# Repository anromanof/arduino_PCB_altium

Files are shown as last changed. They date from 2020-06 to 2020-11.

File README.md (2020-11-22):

# arduino_PCB_altium

Here are the resulting 3D model pictures for quick view. STEP files and 3D pdf's can be found in the corresponding project folder.

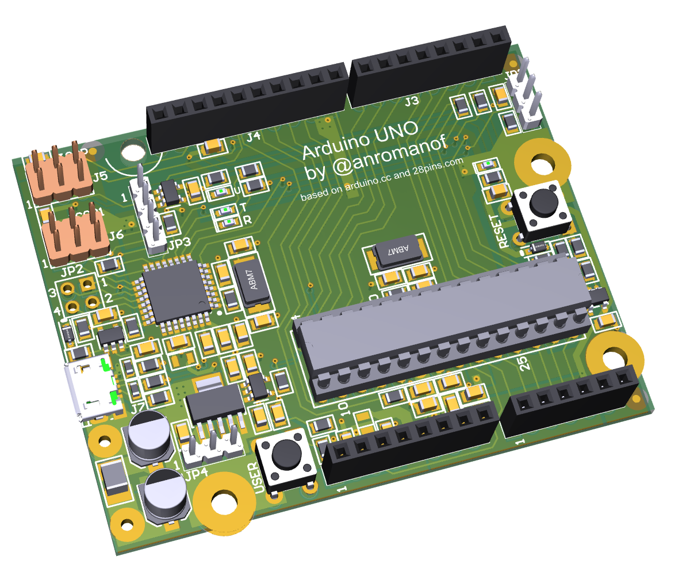
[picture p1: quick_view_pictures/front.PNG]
front


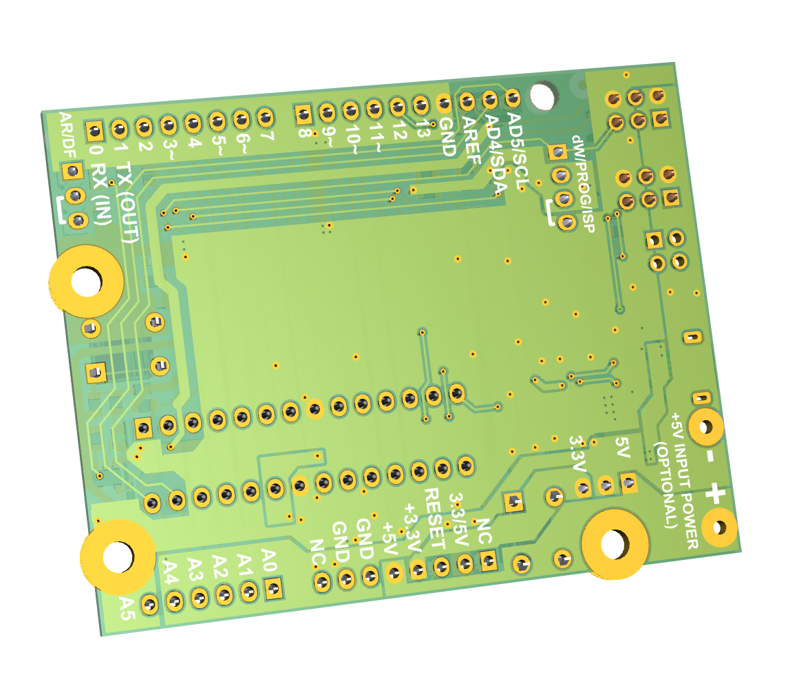
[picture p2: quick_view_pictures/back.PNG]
back


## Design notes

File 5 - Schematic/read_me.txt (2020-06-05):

Update Schematic Cover Page to RELEASED DD-MMM-YYYY
Here is the PDF version of schematic(one for each BOM variant if possible).

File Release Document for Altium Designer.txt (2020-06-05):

Follow this procedure before releasing files. Confirm every action with your initials and date.
IF ANY CHANGES NEEDS TO BE DONE, START THE PROCEDURE FROM BEGINNING!

The procedure needs to be executed in order as defined here. Start from number 1
--------------------------------------------------------------------------------

1) Right Click on the project -> Compile PCB project
I confirm, the project compiles with no errors: 
NR [4-June-2020]

2) Run Design -> Update PCB Document
I confirm, there are no differences between Schematic and PCB: 
NR [4-June-2020]

3) Impedance
I confirm, I have updated and check track width/gap to match required impedance (e.g 55 OHMs): 
NR [4-June-2020]

4) Run Tools -> Polygon Pours -> Rebuild All
I confirm, all polygons have been repoured: 
NR [4-June-2020]

5) Run Tools -> Design Rule Check -> Run Design Rule Check
I confirm, I have checked Design Rule Output File:
NR [4-June-2020]

6) Gerber check
I confirm, I have copied and visually checked gerber files placed in \PCB Manufacturing\Gerber Output\
NR [4-June-2020]

7) Other files
I confirm, I have copied and checked files placed in subdirectories:
NR [4-June-2020]

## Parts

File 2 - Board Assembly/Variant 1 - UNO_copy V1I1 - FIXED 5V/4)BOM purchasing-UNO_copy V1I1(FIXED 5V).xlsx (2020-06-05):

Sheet: Part List Report
 | Component list |  |  | Bill of Materials for Variant [FIXED 5V] of Project [UNO_copy V1I1.PrjPcb] (PCB Document : UNO_copy V1I1_PCB.PcbDoc)
 | Source Data From: | UNO_copy V1I1.PrjPcb |  |  | Contact: |  |  |  | Template created by:
 | Project: | UNO_copy V1I1.PrjPcb
 | Variant: | FIXED 5V |  |  |  |  |  |  | FEDEVEL
 | Report Date: | 6/4/2020 | 10:48 PM |  |  |  |  |  | http://www.fedevel.com
 | Print Date: | 2020-06-04 | 22:48:25
# | Category | Manufacturer 1 | Manufacturer Part Number 1 | Case/Package | Description | Quantity | Supplier 1 | Supplier Part Number 1 | Supplier Order Qty 1 | Supplier Stock 1 | Supplier Unit Price 1 | Supplier Subtotal 1 | Supplier Currency 1
1 | Voltage Regulators - Linear | Texas Instruments | TL1963A-33DCQR | SOT-223 | IC REG LINEAR 3.3V 1.5A SOT223-6 | 1 | Digi-Key | 296-24534-1-ND | 10 | 3415 | 2.51 | 25.13 | USD
2 | Varistors | Bourns | CG0603MLC-05E | 0603 | VARISTOR 0603 | 2 | Digi-Key | CG0603MLC-05ECT-ND | 20 | 11272 | 0.36 | 7.18 | USD
3 | USB Connectors | AMPHENOL ICC (FCI) | 10118193-0001LF |  | CONN USB MICRO B RECPT SMT R/A | 1 | Digi-Key | 609-4616-1-ND | 10 | 147829 | 0.41 | 4.05 | USD
4 | Schottky Diodes | ON Semiconductor / Fairchild | BAT54HT1G |  | Small Signal Schottky Diode, Single, 30 V, 200 mA, 800 mV, 600 mA, 150 C ;RoHS Compliant: Yes | 2 | Digi-Key | BAT54HT1GOSCT-ND | 20 | 328630 | 0.18 | 3.62 | USD
5 | Pushbutton Switches | ALCOSWITCH - TE CONNECTIVITY | 1825910-6 |  | SWITCH TACTILE SPST-NO 0.05A 24V | 2 | Digi-Key | 450-1650-ND | 20 | 25452 | 0.10 | 2.02 | USD
6 | Microcontrollers | Microchip | ATMEGA328P-PU | PDIP | ATMEGA328P-PU; 8 bit Microcontroller AVR 20MHz 1; 32kb Flash; 2kb RAM; I2C SPI 2 | 1 | Digi-Key | ATMEGA328P-PU-ND | 10 | 6233 | 2.08 | 20.80 | USD
7 | Microcontrollers | Microchip | ATMEGA16U2-AU | A | MICROCHIP - ATMEGA16U2-AU - MCU, 8BIT, MEGAAVR, 16MHZ, TQFP-32 | 1 | Digi-Key | ATMEGA16U2-AU-ND | 10 | 3462 | 2.45 | 24.50 | USD
8 | Logic Gates | Texas Instruments | SN74AHC1G09DBVR | SOT-23 | TEXAS INSTRUMENTS - SN74AHC1G09DBVR - AND Gate, 74AHC1G09, 2 Input, 2 V to 5.5 V, SOT-23-5 | 4 | Digi-Key | 296-29202-1-ND | 40 | 27709 | 0.21 | 8.40 | USD
9 | Headers and Wire Housings | Harwin | M20-7820842 | SIL | 2.54mm (0.1") Pitch SIL Vertical PC Tail Socket Assembly, selective gold + tin, 8 contacts | 2 | Digi-Key | 952-1823-ND | 20 | 0 | 0.97 | 19.44 | USD
10 | Headers and Wire Housings | Harwin | M20-7820646 | SIL | 06-WAY SIL VERT SOCKET L/FREE | 1 | Digi-Key | 952-1809-ND | 10 | 1249 | 0.84 | 8.42 | USD
11 | Headers and Wire Housings | Amphenol ICC | 67997-106HLF |  | CONN HEADER 6POS .100 STR 30AU | 2 | Digi-Key | 609-3393-ND | 20 | 1665 | 1.61 | 32.28 | USD
12 | Headers and Wire Housings | Amphenol FCI | 68001-204HLF |  | CONN HEADER VERT 4POS 2.54MM | 1 | Digi-Key | 609-3402-ND | 10 | 3614 | 0.36 | 3.57 | USD
13 | Headers and Wire Housings | Amphenol ICC | 68000-103HLF |  | Conn Unshrouded Header HDR 3 POS 2.54mm Solder ST Thru-Hole Bulk | 1 | Digi-Key | 609-3461-ND | 10 | 15419 | 0.28 | 2.79 | USD
14 | Headers and Wire Housings | Harwin | M20-7821046 | SIL | HARWIN - M20-7821046 - Board-To-Board Connector, M20 Series, Through Hole, Receptacle, 10, 2.54 mm, Tin Plated Contacts | 1 | Digi-Key | 952-1847-ND | 10 | 431 | 1.12 | 11.22 | USD
15 | Fixed Inductors | KEMET | L1210R2R2MDWIT | 1210 | FIXED IND 2.2UH 2A 80 MOHM SMD | 1 | Digi-Key | 399-9598-1-ND | 10 | 660 | 0.48 | 4.79 | USD
16 | Ferrite Beads and Chips | TDK | MPZ2012S601AT000 | 0805 | FERRITE BEAD 600 OHM 0805 1LN | 3 | Digi-Key | 445-2206-1-ND | 30 | 224816 | 0.07 | 2.11 | USD
17 | Diodes | Osram Opto | LGL29K-G2J1-24-Z | 0603 | LED Uni-Color Green 572nm 2-Pin Chip 0603(1608Metric) T/R | 1 | Digi-Key | 475-2709-1-ND | 10 | 120445 | 0.30 | 3.04 | USD
18 | Diodes | Osram Opto | LOL29K-H2K1-24-Z | 0603 | OSRAM - LO L29K-H2K1-24-Z - SMARTLED 0603 ORANGE | 3 | Digi-Key | 475-2740-2-ND |  | 10000 |  |  | USD
19 | Crystals | Abracon | ABM7-16.000MHZ-D2Y-T | CSMD | CRYSTAL 16.0000MHZ 18PF SMD | 2 | Digi-Key | 535-9840-1-ND | 20 | 65890 | 0.89 | 17.72 | USD
20 | Connectors | 3M | 7010501790 |  | CONN IC DIP SOCKET 28POS TIN | 1 | Digi-Key | 3M5480-ND | 10 | 4763 | 0.69 | 6.93 | USD
21 | Connectors | Sullins | QPC02SXGN-RC | 100 | CONN JUMPER SHORTING .100" GOLD | 2 | Digi-Key | S9337-ND | 20 | 389812 | 0.06 | 1.18 | USD
22 | Chip SMD Resistors | Yageo | RC0805FR-071ML | 0805 | RES SMD 1M OHM 1% 1/8W 0805 | 2 | Digi-Key | 311-1.00MCRCT-ND | 20 | 3478595 | 0.04 | 0.80 | USD
23 | Chip SMD Resistors | Yageo | RC0805FR-0710KL | 0805 | RES SMD 10K OHM 1% 1/8W 0805 | 6 | Digi-Key | 311-10.0KCRDKR-ND | 60 | 22153735 | 0.04 | 2.40 | USD
24 | Chip SMD Resistors | Yageo | RC0805FR-0722RL | 0805 | RES SMD 22 OHM 1% 1/8W 0805 | 7 | Digi-Key | 311-22.0CRCT-ND | 70 | 528696 | 0.04 | 2.80 | USD
25 | Chip SMD Resistors | Yageo | RC0805FR-07560RL | 0805 | Res Thick Film 0805 560 Ohm 1% 0.125W(1/8W) ±100ppm/C Pad SMD T/R | 5 | Digi-Key | 311-560CRCT-ND | 50 | 203177 | 0.04 | 2.00 | USD
26 | Chip SMD Resistors | Yageo Phycomp | RC0805FR-071KL | 0805 | RESISTOR, 0805 1K 1%, FULL REEL; Product Range:YAGEO - RC Series; Resistance:1kohm; Power Rating:125mW; Resistance Tolerance:± 1%; Resistor Case Style:0805 [2012 Metric]; Resistor Element Material:Thick Film; Temperature Coefficient:± 250ppm/°C; Voltage Rating:150V; Packaging:Tape & Reel; MSL:-; SVHC:No SVHC (16-Dec-2013); External Depth:0.55mm; External Length / Height:2mm; External Width:1.25mm; No. of Pins:2; Operating Temperature Max:155°C; Operating Temperature Min:-55°C; Operating Temperature Range:-55°C to +155°C; Reel Quantity:5000; Resistor Mounting:SMD; Series:RC12H; Temperature Coef | 3 | Digi-Key | 311-1.00KCRTR-ND |  | 19687706 |  |  | USD
27 | Chip SMD Resistors | Yageo | RC0805JR-070RL | 0805 | Surface Mount Thick Film Resistor, RC Series, 125 mW, - 5%, 150 V, 0805 [2012 Metric] | 2 | Digi-Key | 311-0.0ARCT-ND | 20 | 7980293 | 0.04 | 0.70 | USD
28 | Chip SMD Resistors | Yageo | RC0805FR-07100KL | 0805 | YAGEO RC0805FR-07100KL RES, THICK FILM, 100K, 1%, 0.125W, 0805, REEL | 1 | Digi-Key | 311-100KCRCT-ND | 10 | 4686552 | 0.04 | 0.40 | USD
29 | Ceramic Capacitors | KEMET | C0805C180J5GACTU | 0805 | CAP CER 18PF 50V C0G/NP0 0805 | 4 | Digi-Key | 399-1112-1-ND | 40 | 169363 | 0.10 | 4.00 | USD
30 | Ceramic Capacitors | TDK | C2012X5R1C106K085AC | 0805 | TDK - C2012X5R1C106K085AC - SMD Multilayer Ceramic Capacitor, 10 µF, 16 V, 0805 [2012 Metric], ± 10%, X5R, C Series TDK | 7 | Digi-Key | 445-7644-1-ND | 70 | 1456223 | 0.17 | 12.25 | USD
31 | Ceramic Capacitors | TDK | C2012X5R1E105K125AA | 0805 | TDK - C2012X5R1E105K125AA - SMD Multilayer Ceramic Capacitor, 1 µF, 25 V, 0805 [2012 Metric], ± 10%, X5R, C Series | 1 | Digi-Key | 445-1419-1-ND | 10 | 29808 | 0.18 | 1.82 | USD
32 | Ceramic Capacitors | TDK | C2012X7R1H104K085AA | 0805 | TDK - C2012X7R1H104K085AA - SMD Multilayer Ceramic Capacitor, 0.1 µF, 50 V, 0805 [2012 Metric], ± 10%, X7R, C Series | 19 | Digi-Key | 445-7534-1-ND | 190 | 241464 | 0.06 | 10.66 | USD
33 | Aluminum Electrolytic Capacitors | Panasonic | EEE-1AA101WR | Radial | Cap Aluminum 100uF 10V 20% (5 X 5.4mm) SMD 50mA 1000 hr 85°C T/R | 2 | Digi-Key | PCE3867CT-ND | 20 | 60146 | 0.22 | 4.42 | USD
 |  |  |  |  |  | 94 |  |  | 880 |  |  | 251.44
Approved |  |  |  | Notes
 |  |  |  |  |  | 10 | pcs: | Total |  | 251.44 |  | USD
 |  |  |  |  |  |  |  | Price for 1pcs |  | 25.14 |  | USD

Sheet: Project Information
Project Full Path | C:\Users\Public\Documents\Altium\Projects\UNO_COPY\UNO_copy V1I1.PrjPcb
Project Filename | UNO_copy V1I1.PrjPcb
Variant Name | FIXED 5V
Data-Source Filename | UNO_copy V1I1.PrjPcb
Data-Source Full Path | C:\Users\Public\Documents\Altium\Projects\UNO_COPY\UNO_copy V1I1.PrjPcb
Title | Bill of Materials for Variant [FIXED 5V] of Project [UNO_copy V1I1.PrjPcb] (PCB Document : UNO_copy V1I1_PCB.PcbDoc)
Total Quantity | 94
Report Time | 10:48 PM
Report Date | 6/4/2020
Report Date & Tine | 6/4/2020 10:48 PM
Output Name | Bill of Materials
Output Type | BOM_PartType
Output Generator Name | BOM
Output Generator Description | Bill of Materials

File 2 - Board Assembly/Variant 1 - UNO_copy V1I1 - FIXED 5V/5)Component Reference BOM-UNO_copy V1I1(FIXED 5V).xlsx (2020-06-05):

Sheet: Part List Report
 | Component reference list |  |  | Uno Copy
 |  | Source Data From: | UNO_copy V1I1.PrjPcb |  | Contact: |  | Template created by:
 |  | Project: | UNO_copy V1I1.PrjPcb
 |  | Variant: | FIXED 5V |  |  |  | FEDEVEL
 | Report Date: | 6/4/2020 | 10:53 PM |  |  |  | http://www.fedevel.com
 | Print Date: | 2020-06-04 | 22:53:33
# | Designator | Comment | Description | Manufacturer 1 | Manufacturer Part Number 1 | Case/Package | Supplier 1 | Supplier Part Number 1
1 | C1 | 100uF / 10V | Cap Aluminum 100uF 10V 20% (5 X 5.4mm) SMD 50mA 1000 hr 85°C T/R | Panasonic | EEE-1AA101WR | Radial | Digi-Key | PCE3867CT-ND
2 | C2 | 100uF / 10V | Cap Aluminum 100uF 10V 20% (5 X 5.4mm) SMD 50mA 1000 hr 85°C T/R | Panasonic | EEE-1AA101WR | Radial | Digi-Key | PCE3867CT-ND
3 | C3 | 10uF / 16V | TDK - C2012X5R1C106K085AC - SMD Multilayer Ceramic Capacitor, 10 µF, 16 V, 0805 [2012 Metric], ± 10%, X5R, C Series TDK | TDK | C2012X5R1C106K085AC | 0805 | Digi-Key | 445-7644-1-ND
4 | C4 | 100nF | TDK - C2012X7R1H104K085AA - SMD Multilayer Ceramic Capacitor, 0.1 µF, 50 V, 0805 [2012 Metric], ± 10%, X7R, C Series | TDK | C2012X7R1H104K085AA | 0805 | Digi-Key | 445-7534-1-ND
5 | C5 | 100nF | TDK - C2012X7R1H104K085AA - SMD Multilayer Ceramic Capacitor, 0.1 µF, 50 V, 0805 [2012 Metric], ± 10%, X7R, C Series | TDK | C2012X7R1H104K085AA | 0805 | Digi-Key | 445-7534-1-ND
6 | C6 | 100nF | TDK - C2012X7R1H104K085AA - SMD Multilayer Ceramic Capacitor, 0.1 µF, 50 V, 0805 [2012 Metric], ± 10%, X7R, C Series | TDK | C2012X7R1H104K085AA | 0805 | Digi-Key | 445-7534-1-ND
7 | C7 | 1uF / 25V | TDK - C2012X5R1E105K125AA - SMD Multilayer Ceramic Capacitor, 1 µF, 25 V, 0805 [2012 Metric], ± 10%, X5R, C Series | TDK | C2012X5R1E105K125AA | 0805 | Digi-Key | 445-1419-1-ND
8 | C8 | 100nF | TDK - C2012X7R1H104K085AA - SMD Multilayer Ceramic Capacitor, 0.1 µF, 50 V, 0805 [2012 Metric], ± 10%, X7R, C Series | TDK | C2012X7R1H104K085AA | 0805 | Digi-Key | 445-7534-1-ND
9 | C9 | 18p | CAP CER 18PF 50V C0G/NP0 0805 | KEMET | C0805C180J5GACTU | 0805 | Digi-Key | 399-1112-1-ND
10 | C10 | 18p | CAP CER 18PF 50V C0G/NP0 0805 | KEMET | C0805C180J5GACTU | 0805 | Digi-Key | 399-1112-1-ND
11 | C11 | 100nF | TDK - C2012X7R1H104K085AA - SMD Multilayer Ceramic Capacitor, 0.1 µF, 50 V, 0805 [2012 Metric], ± 10%, X7R, C Series | TDK | C2012X7R1H104K085AA | 0805 | Digi-Key | 445-7534-1-ND
12 | C12 | 10uF / 16V | TDK - C2012X5R1C106K085AC - SMD Multilayer Ceramic Capacitor, 10 µF, 16 V, 0805 [2012 Metric], ± 10%, X5R, C Series TDK | TDK | C2012X5R1C106K085AC | 0805 | Digi-Key | 445-7644-1-ND
13 | C13 | 10uF / 16V | TDK - C2012X5R1C106K085AC - SMD Multilayer Ceramic Capacitor, 10 µF, 16 V, 0805 [2012 Metric], ± 10%, X5R, C Series TDK | TDK | C2012X5R1C106K085AC | 0805 | Digi-Key | 445-7644-1-ND
14 | C14 | 100nF | TDK - C2012X7R1H104K085AA - SMD Multilayer Ceramic Capacitor, 0.1 µF, 50 V, 0805 [2012 Metric], ± 10%, X7R, C Series | TDK | C2012X7R1H104K085AA | 0805 | Digi-Key | 445-7534-1-ND
15 | C15 | 100nF | TDK - C2012X7R1H104K085AA - SMD Multilayer Ceramic Capacitor, 0.1 µF, 50 V, 0805 [2012 Metric], ± 10%, X7R, C Series | TDK | C2012X7R1H104K085AA | 0805 | Digi-Key | 445-7534-1-ND
16 | C16 | 100nF | TDK - C2012X7R1H104K085AA - SMD Multilayer Ceramic Capacitor, 0.1 µF, 50 V, 0805 [2012 Metric], ± 10%, X7R, C Series | TDK | C2012X7R1H104K085AA | 0805 | Digi-Key | 445-7534-1-ND
17 | C17 | 100nF | TDK - C2012X7R1H104K085AA - SMD Multilayer Ceramic Capacitor, 0.1 µF, 50 V, 0805 [2012 Metric], ± 10%, X7R, C Series | TDK | C2012X7R1H104K085AA | 0805 | Digi-Key | 445-7534-1-ND
18 | C19 | 10uF / 16V | TDK - C2012X5R1C106K085AC - SMD Multilayer Ceramic Capacitor, 10 µF, 16 V, 0805 [2012 Metric], ± 10%, X5R, C Series TDK | TDK | C2012X5R1C106K085AC | 0805 | Digi-Key | 445-7644-1-ND
19 | C20 | 100nF | TDK - C2012X7R1H104K085AA - SMD Multilayer Ceramic Capacitor, 0.1 µF, 50 V, 0805 [2012 Metric], ± 10%, X7R, C Series | TDK | C2012X7R1H104K085AA | 0805 | Digi-Key | 445-7534-1-ND
20 | C21 | 10uF / 16V | TDK - C2012X5R1C106K085AC - SMD Multilayer Ceramic Capacitor, 10 µF, 16 V, 0805 [2012 Metric], ± 10%, X5R, C Series TDK | TDK | C2012X5R1C106K085AC | 0805 | Digi-Key | 445-7644-1-ND
21 | C22 | 10uF / 16V | TDK - C2012X5R1C106K085AC - SMD Multilayer Ceramic Capacitor, 10 µF, 16 V, 0805 [2012 Metric], ± 10%, X5R, C Series TDK | TDK | C2012X5R1C106K085AC | 0805 | Digi-Key | 445-7644-1-ND
22 | C23 | 100nF | TDK - C2012X7R1H104K085AA - SMD Multilayer Ceramic Capacitor, 0.1 µF, 50 V, 0805 [2012 Metric], ± 10%, X7R, C Series | TDK | C2012X7R1H104K085AA | 0805 | Digi-Key | 445-7534-1-ND
23 | C24 | 100nF | TDK - C2012X7R1H104K085AA - SMD Multilayer Ceramic Capacitor, 0.1 µF, 50 V, 0805 [2012 Metric], ± 10%, X7R, C Series | TDK | C2012X7R1H104K085AA | 0805 | Digi-Key | 445-7534-1-ND
24 | C25 | 18p | CAP CER 18PF 50V C0G/NP0 0805 | KEMET | C0805C180J5GACTU | 0805 | Digi-Key | 399-1112-1-ND
25 | C26 | 100nF | TDK - C2012X7R1H104K085AA - SMD Multilayer Ceramic Capacitor, 0.1 µF, 50 V, 0805 [2012 Metric], ± 10%, X7R, C Series | TDK | C2012X7R1H104K085AA | 0805 | Digi-Key | 445-7534-1-ND
26 | C27 | 18p | CAP CER 18PF 50V C0G/NP0 0805 | KEMET | C0805C180J5GACTU | 0805 | Digi-Key | 399-1112-1-ND
27 | C28 | 100nF | TDK - C2012X7R1H104K085AA - SMD Multilayer Ceramic Capacitor, 0.1 µF, 50 V, 0805 [2012 Metric], ± 10%, X7R, C Series | TDK | C2012X7R1H104K085AA | 0805 | Digi-Key | 445-7534-1-ND
28 | C29 | 100nF | TDK - C2012X7R1H104K085AA - SMD Multilayer Ceramic Capacitor, 0.1 µF, 50 V, 0805 [2012 Metric], ± 10%, X7R, C Series | TDK | C2012X7R1H104K085AA | 0805 | Digi-Key | 445-7534-1-ND
29 | C30 | 100nF | TDK - C2012X7R1H104K085AA - SMD Multilayer Ceramic Capacitor, 0.1 µF, 50 V, 0805 [2012 Metric], ± 10%, X7R, C Series | TDK | C2012X7R1H104K085AA | 0805 | Digi-Key | 445-7534-1-ND
30 | C31 | 100nF | TDK - C2012X7R1H104K085AA - SMD Multilayer Ceramic Capacitor, 0.1 µF, 50 V, 0805 [2012 Metric], ± 10%, X7R, C Series | TDK | C2012X7R1H104K085AA | 0805 | Digi-Key | 445-7534-1-ND
31 | C32 | 100nF | TDK - C2012X7R1H104K085AA - SMD Multilayer Ceramic Capacitor, 0.1 µF, 50 V, 0805 [2012 Metric], ± 10%, X7R, C Series | TDK | C2012X7R1H104K085AA | 0805 | Digi-Key | 445-7534-1-ND
32 | C33 | 100nF | TDK - C2012X7R1H104K085AA - SMD Multilayer Ceramic Capacitor, 0.1 µF, 50 V, 0805 [2012 Metric], ± 10%, X7R, C Series | TDK | C2012X7R1H104K085AA | 0805 | Digi-Key | 445-7534-1-ND
33 | C34 | 10uF / 16V | TDK - C2012X5R1C106K085AC - SMD Multilayer Ceramic Capacitor, 10 µF, 16 V, 0805 [2012 Metric], ± 10%, X5R, C Series TDK | TDK | C2012X5R1C106K085AC | 0805 | Digi-Key | 445-7644-1-ND
34 | D1 | Green | LED Uni-Color Green 572nm 2-Pin Chip 0603(1608Metric) T/R | Osram Opto | LGL29K-G2J1-24-Z | 0603 | Digi-Key | 475-2709-1-ND
35 | D2 | Orange | OSRAM - LO L29K-H2K1-24-Z - SMARTLED 0603 ORANGE | Osram Opto | LOL29K-H2K1-24-Z | 0603 | Digi-Key | 475-2740-2-ND
36 | D3 | Orange | OSRAM - LO L29K-H2K1-24-Z - SMARTLED 0603 ORANGE | Osram Opto | LOL29K-H2K1-24-Z | 0603 | Digi-Key | 475-2740-2-ND
37 | D4 | Orange | OSRAM - LO L29K-H2K1-24-Z - SMARTLED 0603 ORANGE | Osram Opto | LOL29K-H2K1-24-Z | 0603 | Digi-Key | 475-2740-2-ND
38 | D5 | BAT54HT1G | Small Signal Schottky Diode, Single, 30 V, 200 mA, 800 mV, 600 mA, 150 C ;RoHS Compliant: Yes | ON Semiconductor / Fairchild | BAT54HT1G |  | Digi-Key | BAT54HT1GOSCT-ND
39 | D6 | BAT54HT1G | Small Signal Schottky Diode, Single, 30 V, 200 mA, 800 mV, 600 mA, 150 C ;RoHS Compliant: Yes | ON Semiconductor / Fairchild | BAT54HT1G |  | Digi-Key | BAT54HT1GOSCT-ND
40 | FB1 | MPZ2012S601AT000 | FERRITE BEAD 600 OHM 0805 1LN | TDK | MPZ2012S601AT000 | 0805 | Digi-Key | 445-2206-1-ND
41 | FB2 | MPZ2012S601AT000 | FERRITE BEAD 600 OHM 0805 1LN | TDK | MPZ2012S601AT000 | 0805 | Digi-Key | 445-2206-1-ND
42 | FB3 | MPZ2012S601AT000 | FERRITE BEAD 600 OHM 0805 1LN | TDK | MPZ2012S601AT000 | 0805 | Digi-Key | 445-2206-1-ND
43 | J1 | HDR FMALE 1x8 2.54mm | 2.54mm (0.1") Pitch SIL Vertical PC Tail Socket Assembly, selective gold + tin, 8 contacts | Harwin | M20-7820842 | SIL | Digi-Key | 952-1823-ND
44 | J2 | HDR FMALE 1x6 2.54mm | 06-WAY SIL VERT SOCKET L/FREE | Harwin | M20-7820646 | SIL | Digi-Key | 952-1809-ND
45 | J3 | HDR FMALE 1x8 2.54mm | 2.54mm (0.1") Pitch SIL Vertical PC Tail Socket Assembly, selective gold + tin, 8 contacts | Harwin | M20-7820842 | SIL | Digi-Key | 952-1823-ND
46 | J4 | HDR FMALE 1x10 2.54mm | HARWIN - M20-7821046 - Board-To-Board Connector, M20 Series, Through Hole, Receptacle, 10, 2.54 mm, Tin Plated Contacts | Harwin | M20-7821046 | SIL | Digi-Key | 952-1847-ND
47 | J5 | HDR 2x3 | CONN HEADER 6POS .100 STR 30AU | Amphenol ICC | 67997-106HLF |  | Digi-Key | 609-3393-ND
48 | J6 | HDR 2x3 | CONN HEADER 6POS .100 STR 30AU | Amphenol ICC | 67997-106HLF |  | Digi-Key | 609-3393-ND
49 | J7 | 10118193-0001LF | CONN USB MICRO B RECPT SMT R/A | AMPHENOL ICC (FCI) | 10118193-0001LF |  | Digi-Key | 609-4616-1-ND
50 | JP1 | HDR 1x3 | Conn Unshrouded Header HDR 3 POS 2.54mm Solder ST Thru-Hole Bulk | Amphenol ICC | 68000-103HLF |  | Digi-Key | 609-3461-ND
51 | JP3 | HDR 1x4 | CONN HEADER VERT 4POS 2.54MM | Amphenol FCI | 68001-204HLF |  | Digi-Key | 609-3402-ND
52 | L1 | 2u2 / 2A | FIXED IND 2.2UH 2A 80 MOHM SMD | KEMET | L1210R2R2MDWIT | 1210 | Digi-Key | 399-9598-1-ND
53 | LINK1 | LINK | CONN JUMPER SHORTING .100" GOLD | Sullins | QPC02SXGN-RC | 100 | Digi-Key | S9337-ND
54 | LINK2 | LINK | CONN JUMPER SHORTING .100" GOLD | Sullins | QPC02SXGN-RC | 100 | Digi-Key | S9337-ND
55 | R1 | 100k | YAGEO RC0805FR-07100KL RES, THICK FILM, 100K, 1%, 0.125W, 0805, REEL | Yageo | RC0805FR-07100KL | 0805 | Digi-Key | 311-100KCRCT-ND
56 | R2 | 560R | Res Thick Film 0805 560 Ohm 1% 0.125W(1/8W) ±100ppm/C Pad SMD T/R | Yageo | RC0805FR-07560RL | 0805 | Digi-Key | 311-560CRCT-ND
57 | R3 | 560R | Res Thick Film 0805 560 Ohm 1% 0.125W(1/8W) ±100ppm/C Pad SMD T/R | Yageo | RC0805FR-07560RL | 0805 | Digi-Key | 311-560CRCT-ND
58 | R4 | 10k | RES SMD 10K OHM 1% 1/8W 0805 | Yageo | RC0805FR-0710KL | 0805 | Digi-Key | 311-10.0KCRDKR-ND
59 | R5 | 22R | RES SMD 22 OHM 1% 1/8W 0805 | Yageo | RC0805FR-0722RL | 0805 | Digi-Key | 311-22.0CRCT-ND
60 | R6 | 22R | RES SMD 22 OHM 1% 1/8W 0805 | Yageo | RC0805FR-0722RL | 0805 | Digi-Key | 311-22.0CRCT-ND
61 | R7 | 22R | RES SMD 22 OHM 1% 1/8W 0805 | Yageo | RC0805FR-0722RL | 0805 | Digi-Key | 311-22.0CRCT-ND
62 | R8 | 0R | Surface Mount Thick Film Resistor, RC Series, 125 mW, - 5%, 150 V, 0805 [2012 Metric] | Yageo | RC0805JR-070RL | 0805 | Digi-Key | 311-0.0ARCT-ND
63 | R9 | 1M | RES SMD 1M OHM 1% 1/8W 0805 | Yageo | RC0805FR-071ML | 0805 | Digi-Key | 311-1.00MCRCT-ND
64 | R10 | 1k | RESISTOR, 0805 1K 1%, FULL REEL; Product Range:YAGEO - RC Series; Resistance:1kohm; Power Rating:125mW; Resistance Tolerance:± 1%; Resistor Case Style:0805 [2012 Metric]; Resistor Element Material:Thick Film; Temperature Coefficient:± 250ppm/°C; Voltage Rating:150V; Packaging:Tape & Reel; MSL:-; SVHC:No SVHC (16-Dec-2013); External Depth:0.55mm; External Length / Height:2mm; External Width:1.25mm; No. of Pins:2; Operating Temperature Max:155°C; Operating Temperature Min:-55°C; Operating Temperature Range:-55°C to +155°C; Reel Quantity:5000; Resistor Mounting:SMD; Series:RC12H; Temperature Coef | Yageo Phycomp | RC0805FR-071KL | 0805 | Digi-Key | 311-1.00KCRTR-ND
65 | R11 | 1k | RESISTOR, 0805 1K 1%, FULL REEL; Product Range:YAGEO - RC Series; Resistance:1kohm; Power Rating:125mW; Resistance Tolerance:± 1%; Resistor Case Style:0805 [2012 Metric]; Resistor Element Material:Thick Film; Temperature Coefficient:± 250ppm/°C; Voltage Rating:150V; Packaging:Tape & Reel; MSL:-; SVHC:No SVHC (16-Dec-2013); External Depth:0.55mm; External Length / Height:2mm; External Width:1.25mm; No. of Pins:2; Operating Temperature Max:155°C; Operating Temperature Min:-55°C; Operating Temperature Range:-55°C to +155°C; Reel Quantity:5000; Resistor Mounting:SMD; Series:RC12H; Temperature Coef | Yageo Phycomp | RC0805FR-071KL | 0805 | Digi-Key | 311-1.00KCRTR-ND
66 | R12 | 1k | RESISTOR, 0805 1K 1%, FULL REEL; Product Range:YAGEO - RC Series; Resistance:1kohm; Power Rating:125mW; Resistance Tolerance:± 1%; Resistor Case Style:0805 [2012 Metric]; Resistor Element Material:Thick Film; Temperature Coefficient:± 250ppm/°C; Voltage Rating:150V; Packaging:Tape & Reel; MSL:-; SVHC:No SVHC (16-Dec-2013); External Depth:0.55mm; External Length / Height:2mm; External Width:1.25mm; No. of Pins:2; Operating Temperature Max:155°C; Operating Temperature Min:-55°C; Operating Temperature Range:-55°C to +155°C; Reel Quantity:5000; Resistor Mounting:SMD; Series:RC12H; Temperature Coef | Yageo Phycomp | RC0805FR-071KL | 0805 | Digi-Key | 311-1.00KCRTR-ND
67 | R13 | 22R | RES SMD 22 OHM 1% 1/8W 0805 | Yageo | RC0805FR-0722RL | 0805 | Digi-Key | 311-22.0CRCT-ND
68 | R14 | 10k | RES SMD 10K OHM 1% 1/8W 0805 | Yageo | RC0805FR-0710KL | 0805 | Digi-Key | 311-10.0KCRDKR-ND
69 | R15 | 560R | Res Thick Film 0805 560 Ohm 1% 0.125W(1/8W) ±100ppm/C Pad SMD T/R | Yageo | RC0805FR-07560RL | 0805 | Digi-Key | 311-560CRCT-ND
70 | R16 | 1M | RES SMD 1M OHM 1% 1/8W 0805 | Yageo | RC0805FR-071ML | 0805 | Digi-Key | 311-1.00MCRCT-ND
71 | R17 | 560R | Res Thick Film 0805 560 Ohm 1% 0.125W(1/8W) ±100ppm/C Pad SMD T/R | Yageo | RC0805FR-07560RL | 0805 | Digi-Key | 311-560CRCT-ND
72 | R18 | 10k | RES SMD 10K OHM 1% 1/8W 0805 | Yageo | RC0805FR-0710KL | 0805 | Digi-Key | 311-10.0KCRDKR-ND
73 | R19 | 10k | RES SMD 10K OHM 1% 1/8W 0805 | Yageo | RC0805FR-0710KL | 0805 | Digi-Key | 311-10.0KCRDKR-ND
74 | R20 | 10k | RES SMD 10K OHM 1% 1/8W 0805 | Yageo | RC0805FR-0710KL | 0805 | Digi-Key | 311-10.0KCRDKR-ND
75 | R21 | 10k | RES SMD 10K OHM 1% 1/8W 0805 | Yageo | RC0805FR-0710KL | 0805 | Digi-Key | 311-10.0KCRDKR-ND
76 | R22 | 560R | Res Thick Film 0805 560 Ohm 1% 0.125W(1/8W) ±100ppm/C Pad SMD T/R | Yageo | RC0805FR-07560RL | 0805 | Digi-Key | 311-560CRCT-ND
77 | R23 | 22R | RES SMD 22 OHM 1% 1/8W 0805 | Yageo | RC0805FR-0722RL | 0805 | Digi-Key | 311-22.0CRCT-ND
78 | R24 | 22R | RES SMD 22 OHM 1% 1/8W 0805 | Yageo | RC0805FR-0722RL | 0805 | Digi-Key | 311-22.0CRCT-ND
79 | R25 | 22R | RES SMD 22 OHM 1% 1/8W 0805 | Yageo | RC0805FR-0722RL | 0805 | Digi-Key | 311-22.0CRCT-ND
80 | R27 | 0R | Surface Mount Thick Film Resistor, RC Series, 125 mW, - 5%, 150 V, 0805 [2012 Metric] | Yageo | RC0805JR-070RL | 0805 | Digi-Key | 311-0.0ARCT-ND
81 | SCKT FOR U1 | 28-DIP Socket | CONN IC DIP SOCKET 28POS TIN | 3M | 7010501790 |  | Digi-Key | 3M5480-ND
82 | SW1 | 1825910-6 | SWITCH TACTILE SPST-NO 0.05A 24V | ALCOSWITCH - TE CONNECTIVITY | 1825910-6 |  | Digi-Key | 450-1650-ND
83 | SW2 | 1825910-6 | SWITCH TACTILE SPST-NO 0.05A 24V | ALCOSWITCH - TE CONNECTIVITY | 1825910-6 |  | Digi-Key | 450-1650-ND
84 | U1 | ATMEGA328P-PU | ATMEGA328P-PU; 8 bit Microcontroller AVR 20MHz 1; 32kb Flash; 2kb RAM; I2C SPI 2 | Microchip | ATMEGA328P-PU | PDIP | Digi-Key | ATMEGA328P-PU-ND
85 | U2 | ATMEGA16U2-AU | MICROCHIP - ATMEGA16U2-AU - MCU, 8BIT, MEGAAVR, 16MHZ, TQFP-32 | Microchip | ATMEGA16U2-AU | A | Digi-Key | ATMEGA16U2-AU-ND
86 | U3 | TL1963A-33DCQR | IC REG LINEAR 3.3V 1.5A SOT223-6 | Texas Instruments | TL1963A-33DCQR | SOT-223 | Digi-Key | 296-24534-1-ND
87 | U4 | SN74AHC1G09DBVR | TEXAS INSTRUMENTS - SN74AHC1G09DBVR - AND Gate, 74AHC1G09, 2 Input, 2 V to 5.5 V, SOT-23-5 | Texas Instruments | SN74AHC1G09DBVR | SOT-23 | Digi-Key | 296-29202-1-ND
88 | U5 | SN74AHC1G09DBVR | TEXAS INSTRUMENTS - SN74AHC1G09DBVR - AND Gate, 74AHC1G09, 2 Input, 2 V to 5.5 V, SOT-23-5 | Texas Instruments | SN74AHC1G09DBVR | SOT-23 | Digi-Key | 296-29202-1-ND
89 | U6 | SN74AHC1G09DBVR | TEXAS INSTRUMENTS - SN74AHC1G09DBVR - AND Gate, 74AHC1G09, 2 Input, 2 V to 5.5 V, SOT-23-5 | Texas Instruments | SN74AHC1G09DBVR | SOT-23 | Digi-Key | 296-29202-1-ND
90 | U7 | SN74AHC1G09DBVR | TEXAS INSTRUMENTS - SN74AHC1G09DBVR - AND Gate, 74AHC1G09, 2 Input, 2 V to 5.5 V, SOT-23-5 | Texas Instruments | SN74AHC1G09DBVR | SOT-23 | Digi-Key | 296-29202-1-ND
91 | Y1 | ABM7-16.000MHZ-D2Y-T | CRYSTAL 16.0000MHZ 18PF SMD | Abracon | ABM7-16.000MHZ-D2Y-T | CSMD | Digi-Key | 535-9840-1-ND
92 | Y2 | ABM7-16.000MHZ-D2Y-T | CRYSTAL 16.0000MHZ 18PF SMD | Abracon | ABM7-16.000MHZ-D2Y-T | CSMD | Digi-Key | 535-9840-1-ND
93 | Z1 | CG0603MLC-05E | VARISTOR 0603 | Bourns | CG0603MLC-05E | 0603 | Digi-Key | CG0603MLC-05ECT-ND
94 | Z2 | CG0603MLC-05E | VARISTOR 0603 | Bourns | CG0603MLC-05E | 0603 | Digi-Key | CG0603MLC-05ECT-ND
Approved |  |  |  | Notes

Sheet: Project Information
Project Full Path | C:\Users\Public\Documents\Altium\Projects\UNO_COPY\UNO_copy V1I1.PrjPcb
Project Filename | UNO_copy V1I1.PrjPcb
Variant Name | FIXED 5V
Data-Source Filename | UNO_copy V1I1.PrjPcb
Data-Source Full Path | C:\Users\Public\Documents\Altium\Projects\UNO_COPY\UNO_copy V1I1.PrjPcb
Title | UNO_copy V1I1.PrjPcb
Total Quantity | 94
Report Time | 10:53 PM
Report Date | 6/4/2020
Report Date & Tine | 6/4/2020 10:53 PM
Output Name | Component Reference BOM
Output Type | BOM_PartType
Output Generator Name | BOM
Output Generator Description | Bill of Materials

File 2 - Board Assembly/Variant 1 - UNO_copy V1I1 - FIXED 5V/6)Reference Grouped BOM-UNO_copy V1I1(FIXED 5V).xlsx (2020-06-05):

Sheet: Part List Report
 | Component reference list (grouped) |  |  |  | Uno Copy
 | Source Data From: |  | UNO_copy V1I1.PrjPcb |  |  | Contact: |  | Template created by:
 | Project: |  | UNO_copy V1I1.PrjPcb
 | Variant: |  | FIXED 5V |  |  |  |  | FEDEVEL
 | Report Date: |  | 6/4/2020 | 11:02 PM |  |  |  | http://www.fedevel.com
 | Print Date: |  | 2020-06-04 | 23:04:06
# | Designator | Quantity | Comment | Description | Manufacturer 1 | Manufacturer Part Number 1 | Case/Package | Supplier 1 | Supplier Part Number 1
1 | C1, C2 | 2 | 100uF / 10V | Cap Aluminum 100uF 10V 20% (5 X 5.4mm) SMD 50mA 1000 hr 85°C T/R | Panasonic | EEE-1AA101WR | Radial | Digi-Key | PCE3867CT-ND
2 | C3, C12, C13, C19, C21, C22, C34 | 7 | 10uF / 16V | TDK - C2012X5R1C106K085AC - SMD Multilayer Ceramic Capacitor, 10 µF, 16 V, 0805 [2012 Metric], ± 10%, X5R, C Series TDK | TDK | C2012X5R1C106K085AC | 0805 | Digi-Key | 445-7644-1-ND
3 | C4, C5, C6, C8, C11, C14, C15, C16, C17, C20, C23, C24, C26, C28, C29, C30, C31, C32, C33 | 19 | 100nF | TDK - C2012X7R1H104K085AA - SMD Multilayer Ceramic Capacitor, 0.1 µF, 50 V, 0805 [2012 Metric], ± 10%, X7R, C Series | TDK | C2012X7R1H104K085AA | 0805 | Digi-Key | 445-7534-1-ND
4 | C7 | 1 | 1uF / 25V | TDK - C2012X5R1E105K125AA - SMD Multilayer Ceramic Capacitor, 1 µF, 25 V, 0805 [2012 Metric], ± 10%, X5R, C Series | TDK | C2012X5R1E105K125AA | 0805 | Digi-Key | 445-1419-1-ND
5 | C9, C10, C25, C27 | 4 | 18p | CAP CER 18PF 50V C0G/NP0 0805 | KEMET | C0805C180J5GACTU | 0805 | Digi-Key | 399-1112-1-ND
6 | D1 | 1 | Green | LED Uni-Color Green 572nm 2-Pin Chip 0603(1608Metric) T/R | Osram Opto | LGL29K-G2J1-24-Z | 0603 | Digi-Key | 475-2709-1-ND
7 | D2, D3, D4 | 3 | Orange | OSRAM - LO L29K-H2K1-24-Z - SMARTLED 0603 ORANGE | Osram Opto | LOL29K-H2K1-24-Z | 0603 | Digi-Key | 475-2740-2-ND
8 | D5, D6 | 2 | BAT54HT1G | Small Signal Schottky Diode, Single, 30 V, 200 mA, 800 mV, 600 mA, 150 C ;RoHS Compliant: Yes | ON Semiconductor / Fairchild | BAT54HT1G |  | Digi-Key | BAT54HT1GOSCT-ND
9 | FB1, FB2, FB3 | 3 | MPZ2012S601AT000 | FERRITE BEAD 600 OHM 0805 1LN | TDK | MPZ2012S601AT000 | 0805 | Digi-Key | 445-2206-1-ND
10 | J1, J3 | 2 | HDR FMALE 1x8 2.54mm | 2.54mm (0.1") Pitch SIL Vertical PC Tail Socket Assembly, selective gold + tin, 8 contacts | Harwin | M20-7820842 | SIL | Digi-Key | 952-1823-ND
11 | J2 | 1 | HDR FMALE 1x6 2.54mm | 06-WAY SIL VERT SOCKET L/FREE | Harwin | M20-7820646 | SIL | Digi-Key | 952-1809-ND
12 | J4 | 1 | HDR FMALE 1x10 2.54mm | HARWIN - M20-7821046 - Board-To-Board Connector, M20 Series, Through Hole, Receptacle, 10, 2.54 mm, Tin Plated Contacts | Harwin | M20-7821046 | SIL | Digi-Key | 952-1847-ND
13 | J5, J6 | 2 | HDR 2x3 | CONN HEADER 6POS .100 STR 30AU | Amphenol ICC | 67997-106HLF |  | Digi-Key | 609-3393-ND
14 | J7 | 1 | 10118193-0001LF | CONN USB MICRO B RECPT SMT R/A | AMPHENOL ICC (FCI) | 10118193-0001LF |  | Digi-Key | 609-4616-1-ND
15 | JP1 | 1 | HDR 1x3 | Conn Unshrouded Header HDR 3 POS 2.54mm Solder ST Thru-Hole Bulk | Amphenol ICC | 68000-103HLF |  | Digi-Key | 609-3461-ND
16 | JP3 | 1 | HDR 1x4 | CONN HEADER VERT 4POS 2.54MM | Amphenol FCI | 68001-204HLF |  | Digi-Key | 609-3402-ND
17 | L1 | 1 | 2u2 / 2A | FIXED IND 2.2UH 2A 80 MOHM SMD | KEMET | L1210R2R2MDWIT | 1210 | Digi-Key | 399-9598-1-ND
18 | LINK1, LINK2 | 2 | LINK | CONN JUMPER SHORTING .100" GOLD | Sullins | QPC02SXGN-RC | 100 | Digi-Key | S9337-ND
19 | R1 | 1 | 100k | YAGEO RC0805FR-07100KL RES, THICK FILM, 100K, 1%, 0.125W, 0805, REEL | Yageo | RC0805FR-07100KL | 0805 | Digi-Key | 311-100KCRCT-ND
20 | R2, R3, R15, R17, R22 | 5 | 560R | Res Thick Film 0805 560 Ohm 1% 0.125W(1/8W) ±100ppm/C Pad SMD T/R | Yageo | RC0805FR-07560RL | 0805 | Digi-Key | 311-560CRCT-ND
21 | R4, R14, R18, R19, R20, R21 | 6 | 10k | RES SMD 10K OHM 1% 1/8W 0805 | Yageo | RC0805FR-0710KL | 0805 | Digi-Key | 311-10.0KCRDKR-ND
22 | R5, R6, R7, R13, R23, R24, R25 | 7 | 22R | RES SMD 22 OHM 1% 1/8W 0805 | Yageo | RC0805FR-0722RL | 0805 | Digi-Key | 311-22.0CRCT-ND
23 | R8, R27 | 2 | 0R | Surface Mount Thick Film Resistor, RC Series, 125 mW, - 5%, 150 V, 0805 [2012 Metric] | Yageo | RC0805JR-070RL | 0805 | Digi-Key | 311-0.0ARCT-ND
24 | R9, R16 | 2 | 1M | RES SMD 1M OHM 1% 1/8W 0805 | Yageo | RC0805FR-071ML | 0805 | Digi-Key | 311-1.00MCRCT-ND
25 | R10, R11, R12 | 3 | 1k | RESISTOR, 0805 1K 1%, FULL REEL; Product Range:YAGEO - RC Series; Resistance:1kohm; Power Rating:125mW; Resistance Tolerance:± 1%; Resistor Case Style:0805 [2012 Metric]; Resistor Element Material:Thick Film; Temperature Coefficient:± 250ppm/°C; Voltage Rating:150V; Packaging:Tape & Reel; MSL:-; SVHC:No SVHC (16-Dec-2013); External Depth:0.55mm; External Length / Height:2mm; External Width:1.25mm; No. of Pins:2; Operating Temperature Max:155°C; Operating Temperature Min:-55°C; Operating Temperature Range:-55°C to +155°C; Reel Quantity:5000; Resistor Mounting:SMD; Series:RC12H; Temperature Coef | Yageo Phycomp | RC0805FR-071KL | 0805 | Digi-Key | 311-1.00KCRTR-ND
26 | SCKT FOR U1 | 1 | 28-DIP Socket | CONN IC DIP SOCKET 28POS TIN | 3M | 7010501790 |  | Digi-Key | 3M5480-ND
27 | SW1, SW2 | 2 | 1825910-6 | SWITCH TACTILE SPST-NO 0.05A 24V | ALCOSWITCH - TE CONNECTIVITY | 1825910-6 |  | Digi-Key | 450-1650-ND
28 | U1 | 1 | ATMEGA328P-PU | ATMEGA328P-PU; 8 bit Microcontroller AVR 20MHz 1; 32kb Flash; 2kb RAM; I2C SPI 2 | Microchip | ATMEGA328P-PU | PDIP | Digi-Key | ATMEGA328P-PU-ND
29 | U2 | 1 | ATMEGA16U2-AU | MICROCHIP - ATMEGA16U2-AU - MCU, 8BIT, MEGAAVR, 16MHZ, TQFP-32 | Microchip | ATMEGA16U2-AU | A | Digi-Key | ATMEGA16U2-AU-ND
30 | U3 | 1 | TL1963A-33DCQR | IC REG LINEAR 3.3V 1.5A SOT223-6 | Texas Instruments | TL1963A-33DCQR | SOT-223 | Digi-Key | 296-24534-1-ND
31 | U4, U5, U6, U7 | 4 | SN74AHC1G09DBVR | TEXAS INSTRUMENTS - SN74AHC1G09DBVR - AND Gate, 74AHC1G09, 2 Input, 2 V to 5.5 V, SOT-23-5 | Texas Instruments | SN74AHC1G09DBVR | SOT-23 | Digi-Key | 296-29202-1-ND
32 | Y1, Y2 | 2 | ABM7-16.000MHZ-D2Y-T | CRYSTAL 16.0000MHZ 18PF SMD | Abracon | ABM7-16.000MHZ-D2Y-T | CSMD | Digi-Key | 535-9840-1-ND
33 | Z1, Z2 | 2 | CG0603MLC-05E | VARISTOR 0603 | Bourns | CG0603MLC-05E | 0603 | Digi-Key | CG0603MLC-05ECT-ND
Approved |  |  |  |  | Notes

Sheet: Project Information
Project Full Path | C:\Users\Public\Documents\Altium\Projects\UNO_COPY\UNO_copy V1I1.PrjPcb
Project Filename | UNO_copy V1I1.PrjPcb
Variant Name | FIXED 5V
Data-Source Filename | UNO_copy V1I1.PrjPcb
Data-Source Full Path | C:\Users\Public\Documents\Altium\Projects\UNO_COPY\UNO_copy V1I1.PrjPcb
Title | UNO_copy V1I1.PrjPcb
Total Quantity | 94
Report Time | 11:02 PM
Report Date | 6/4/2020
Report Date & Tine | 6/4/2020 11:02 PM
Output Name | Reference Grouped BOM
Output Type | BOM_PartType
Output Generator Name | BOM
Output Generator Description | Bill of Materials

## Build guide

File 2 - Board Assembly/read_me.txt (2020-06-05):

The following files are placed here:

- Mechanical Drawing (Board dimensions, holes position, ..)
- TOP and BOTTOM Assembly Drawing (Component position with Reference Designator)
- TOP and BOTTOM VIEW (shows board outline, assembly layer, TOP + BOTTOM layers)
- Bill of Materials (grouped by component type)
- Component reference BOM (each component on one line: Designator, Description, Manufacturer 1,
  Manufacturer, Part Number 1, Package / Case, Supplier 1, Supplier Part Number 1)
- Component reference BOM (as above) grouped by component type.
- Pick and Place
- TOP and BOTTOM Layer + TOP and BOTTOM Paste Gerber Files (for stencil - if panel is done in a PCB house, ask them later for the top/bottom layers and paste for the panel)
- PDF 3D Model

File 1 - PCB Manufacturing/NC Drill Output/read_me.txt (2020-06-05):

Here are the drill files and documents which explain it (e.g. for HDI PCB, pdf showing drills for each layer pair)

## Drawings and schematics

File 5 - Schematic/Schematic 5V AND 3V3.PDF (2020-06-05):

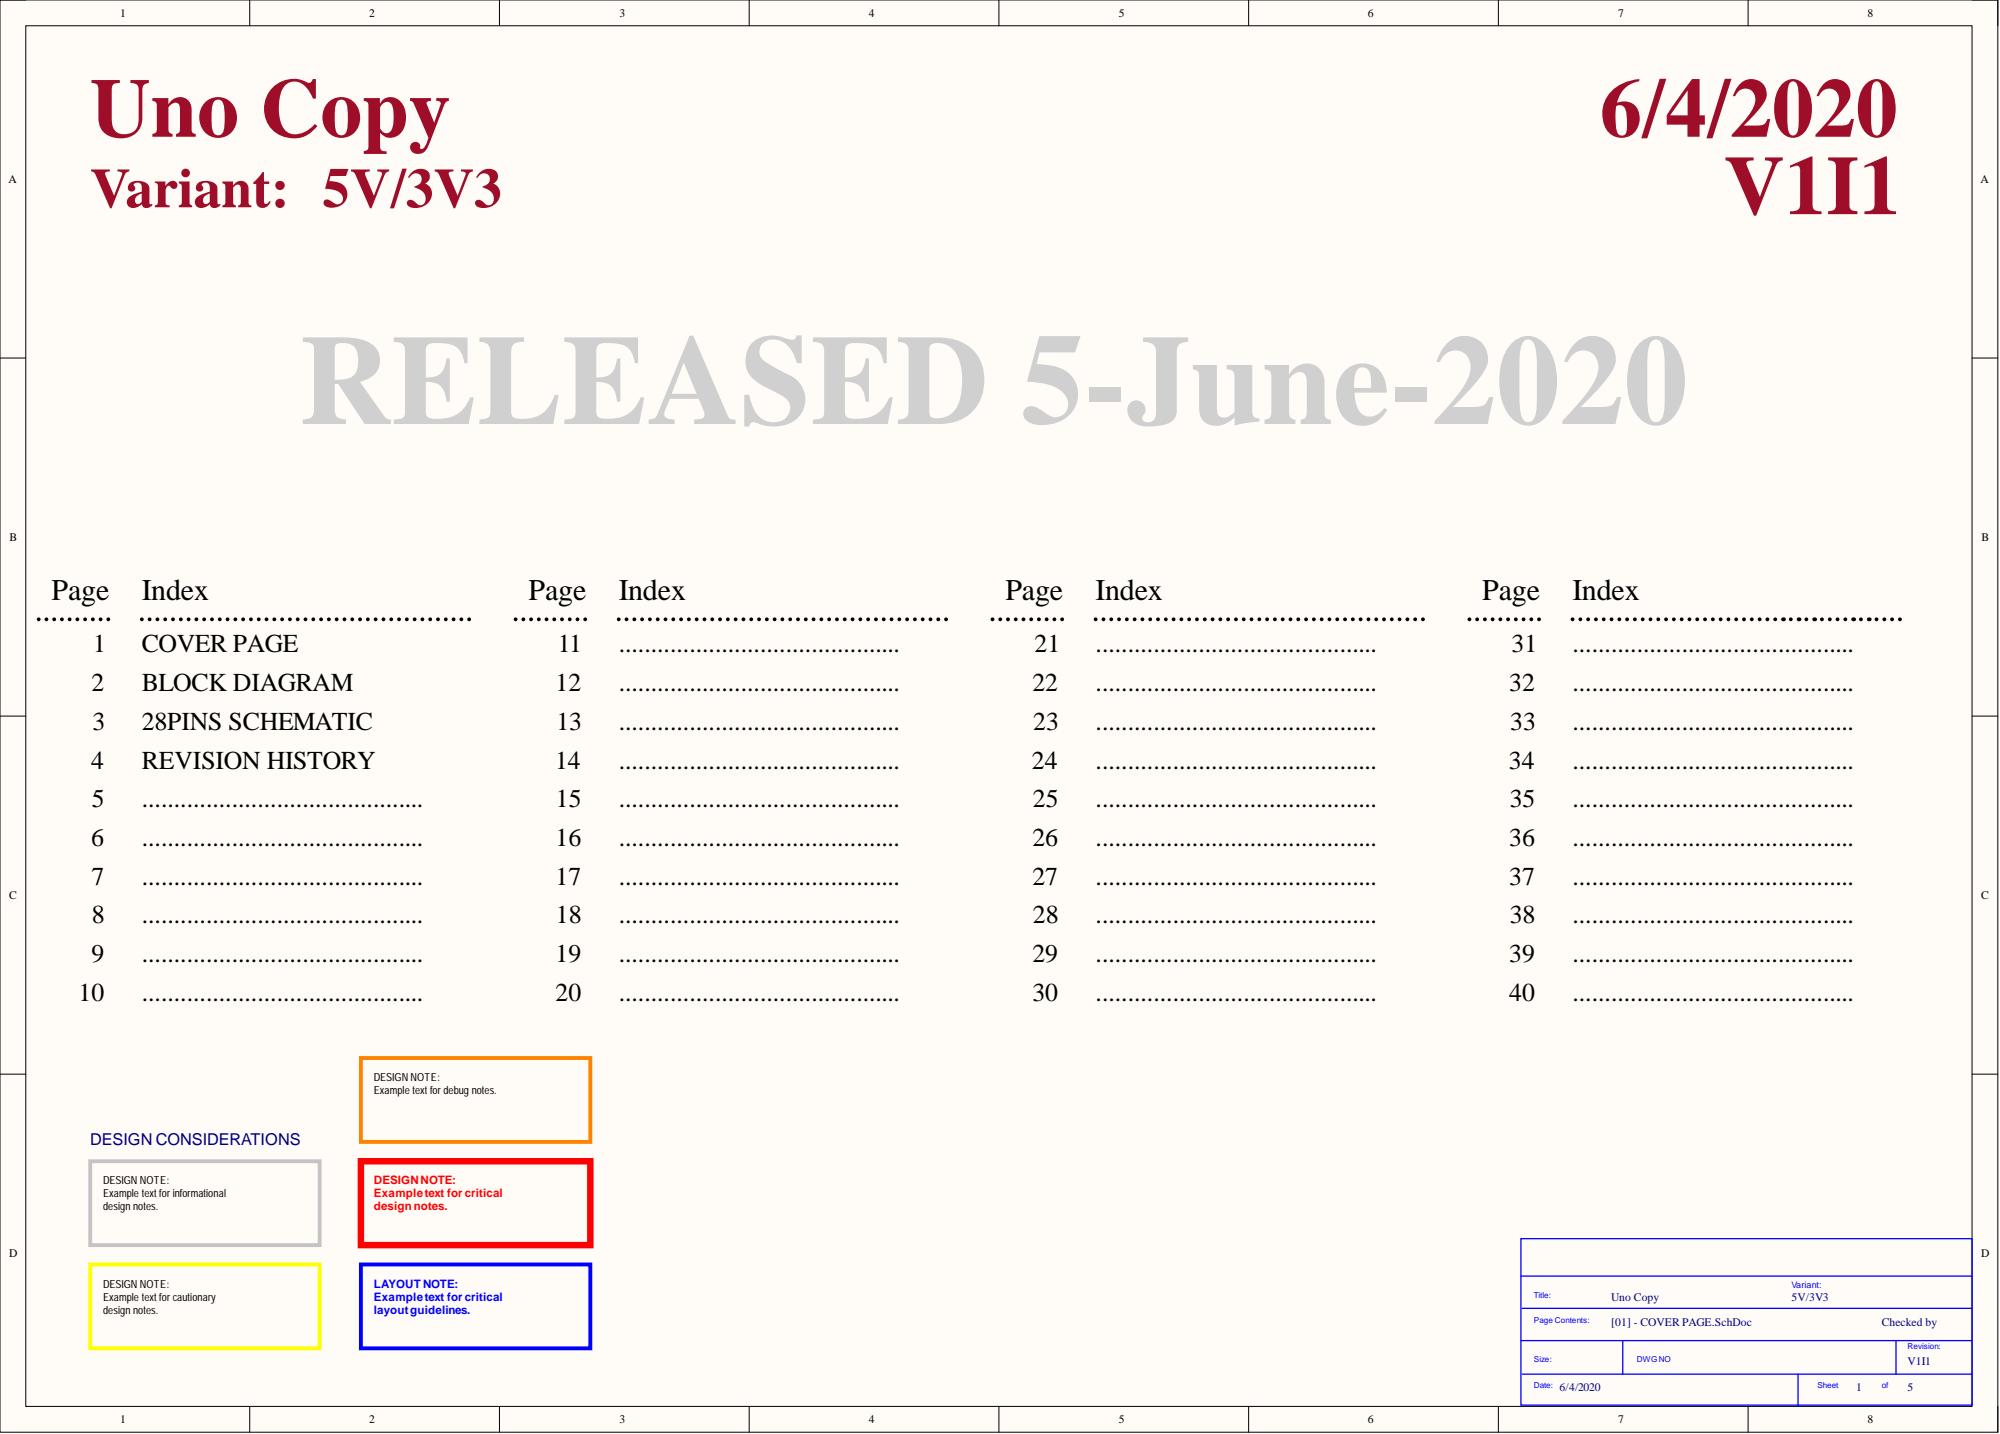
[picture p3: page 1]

DESIGN NOTE:
Example text for debug notes.

Example text for informational
design notes.

Example text for critical

Example text for cautionary

LAYOUT NOTE:
layout guidelines.

Size: | DWG NO | Revision: V1I1

Date: | Sheet of

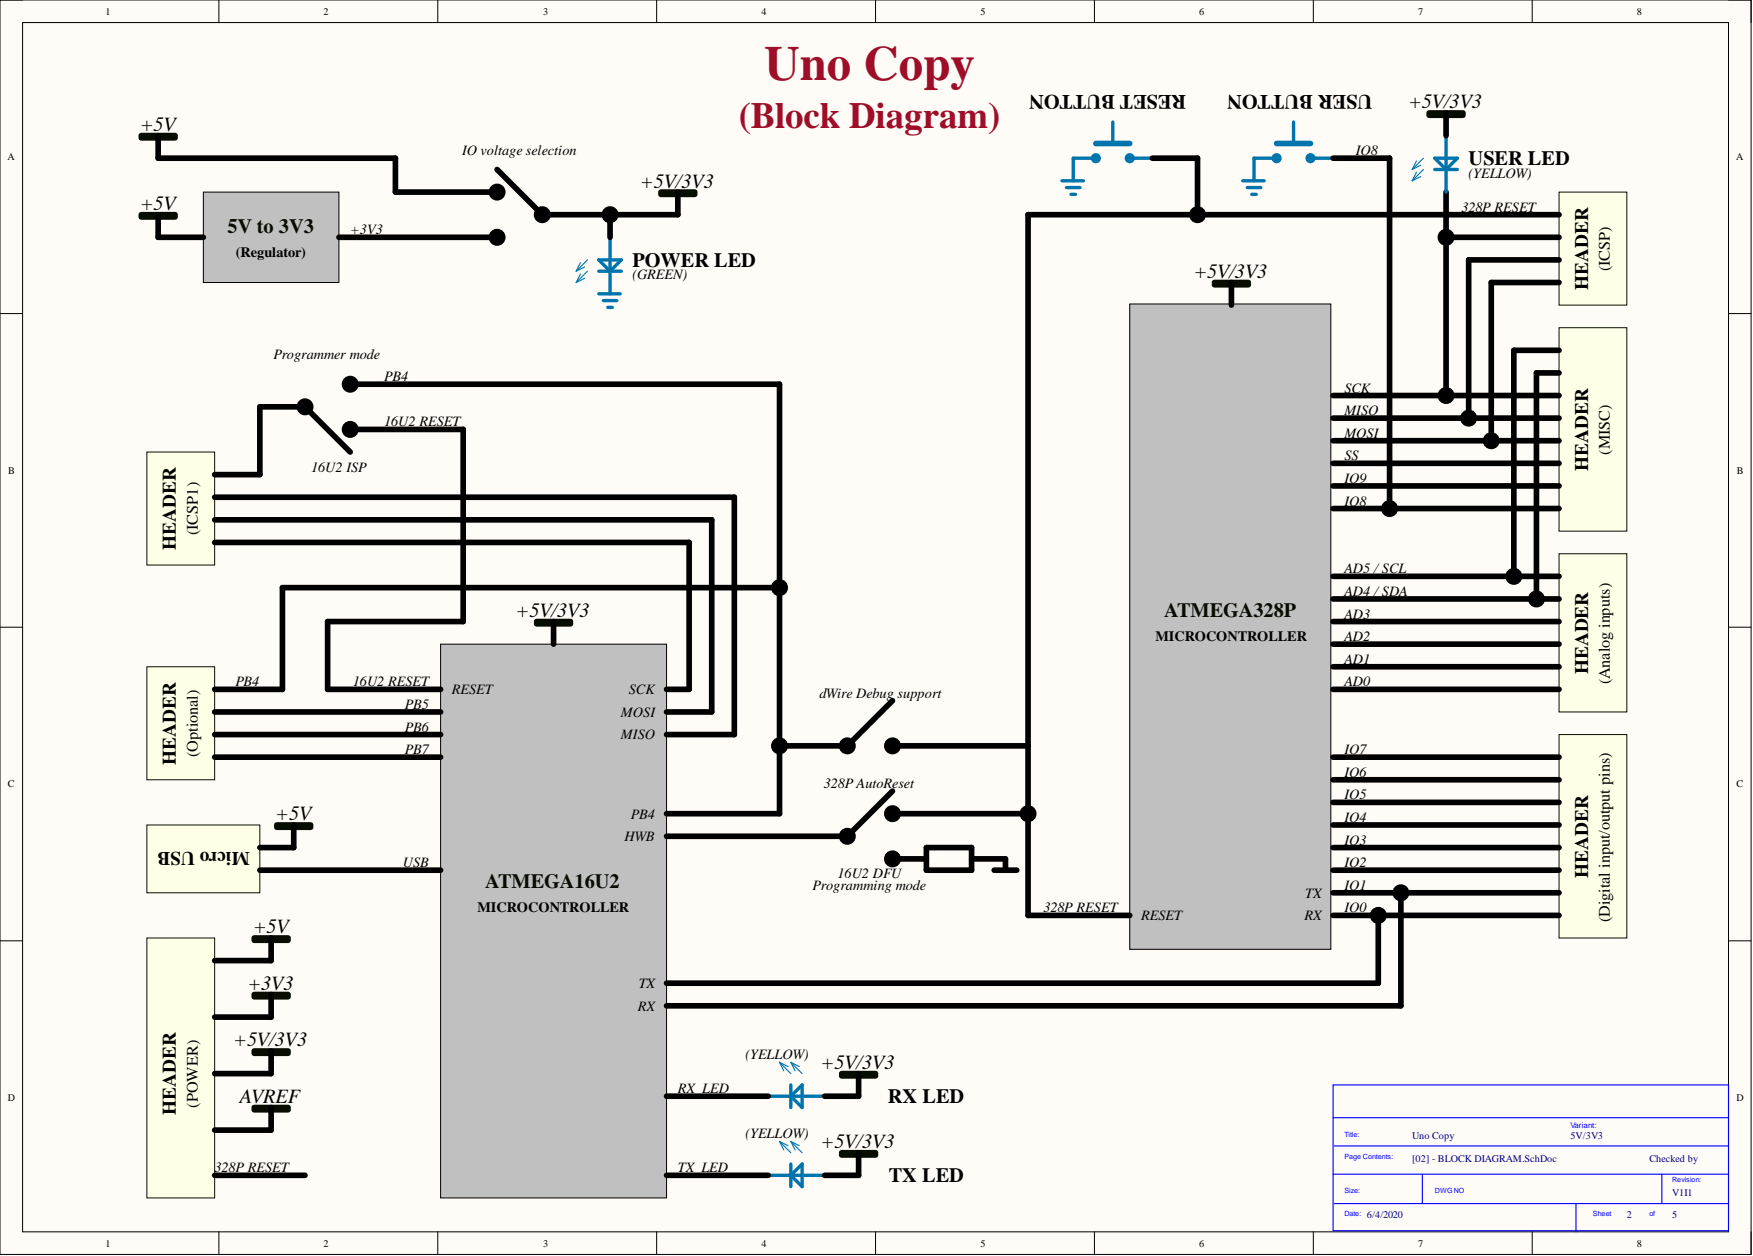
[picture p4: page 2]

MISO
MOSI
SS
IO9
IO8

AD5 / SCL
AD4 / SDA

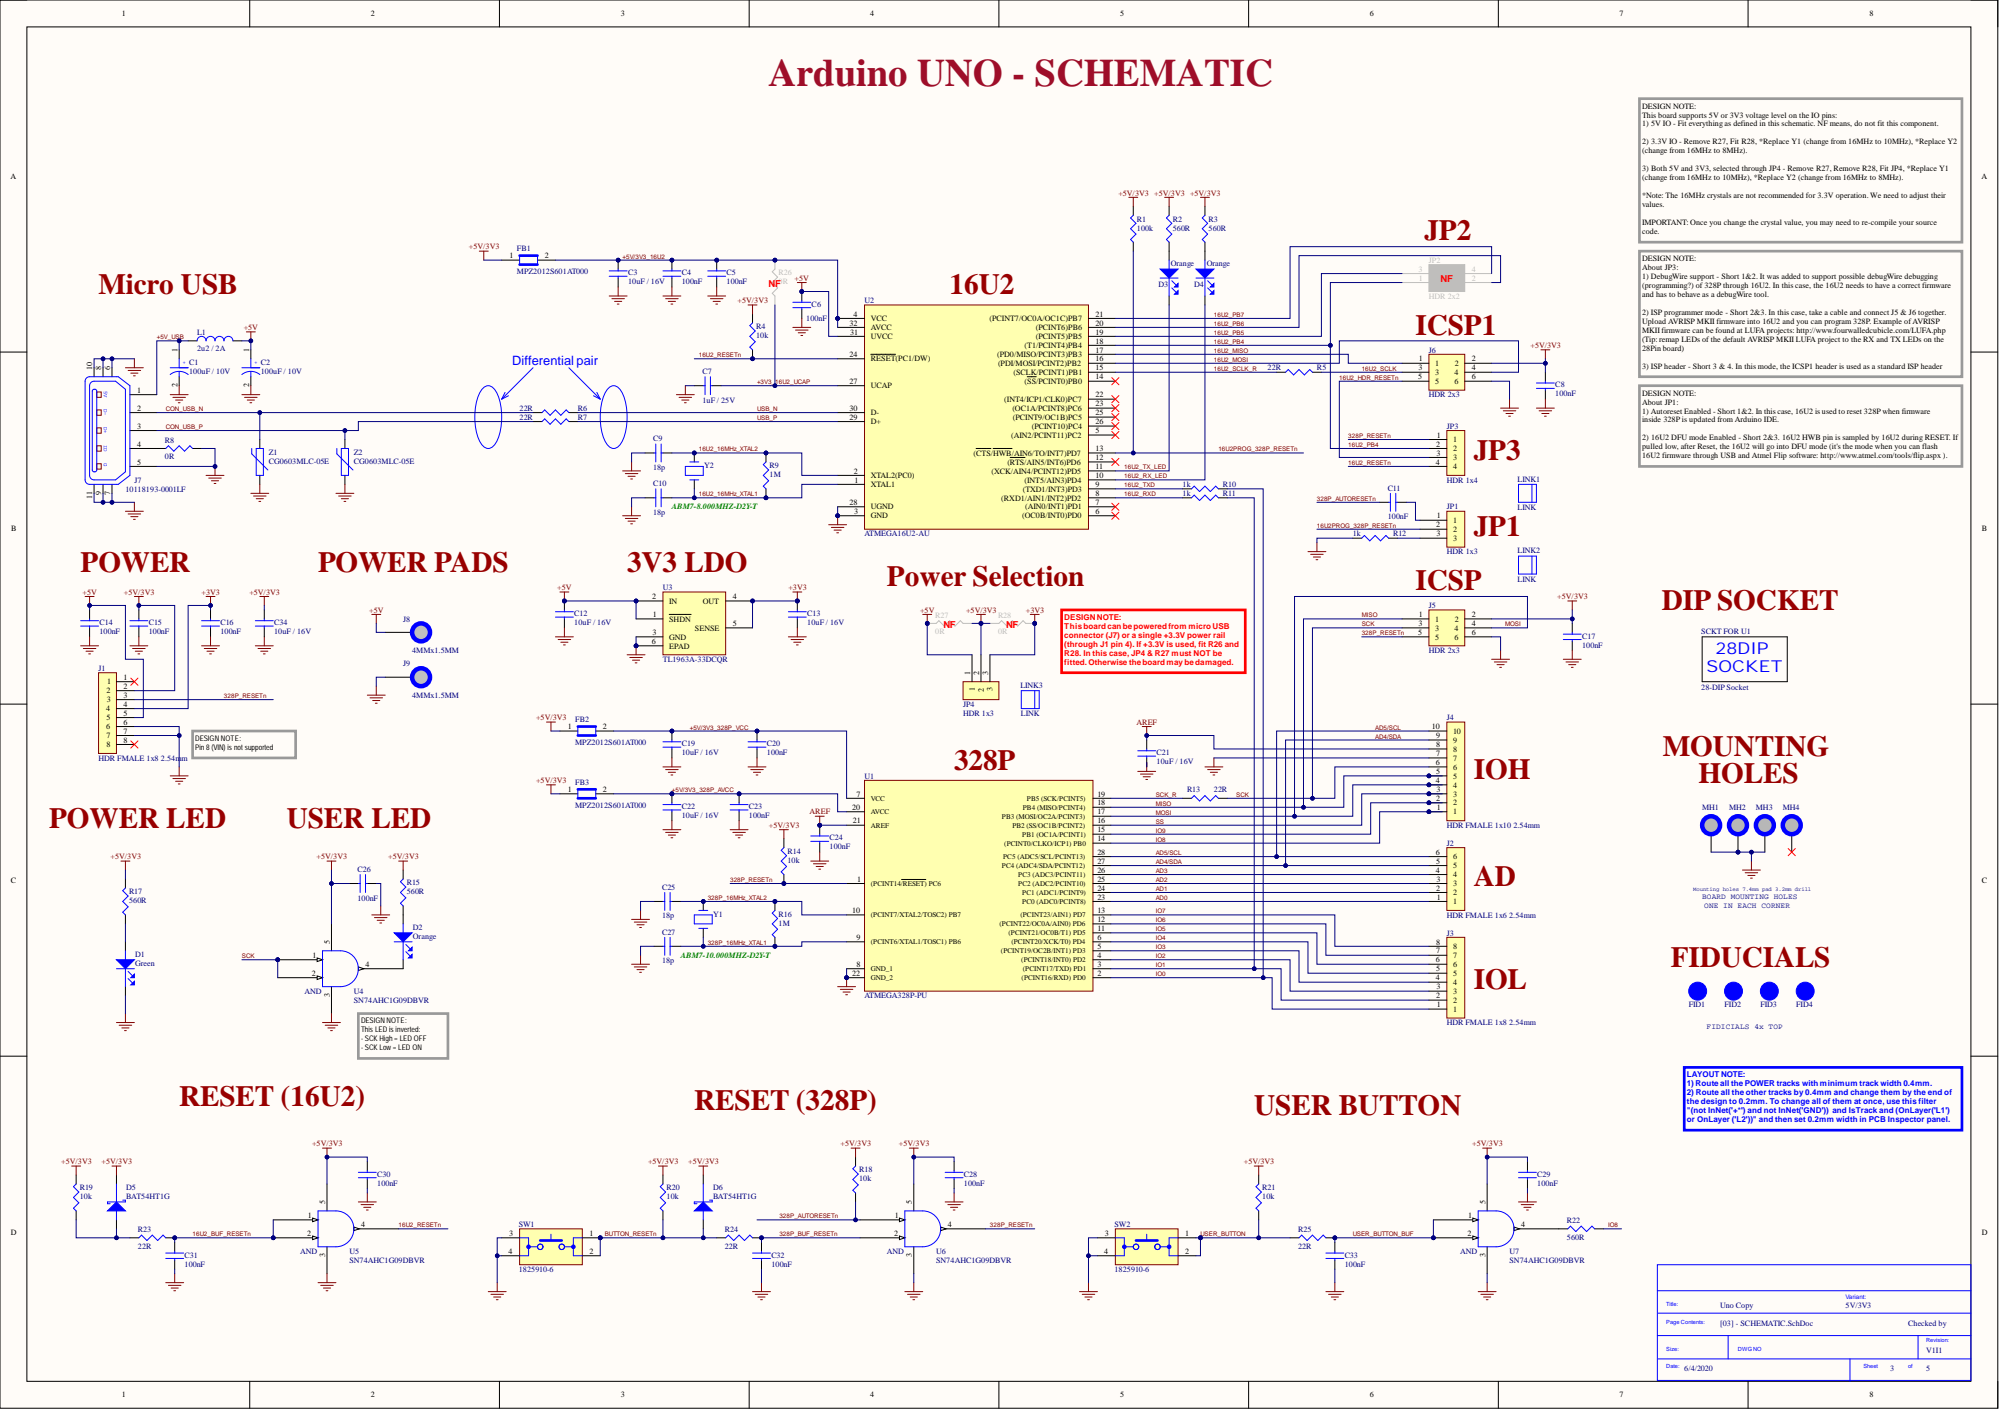
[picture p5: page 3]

DESIGN NOTE:
This board supports 5V or 3V3 voltage level on the IO pins:
1) 5V IO - Fit everything as defined in this schematic. NF means, do not fit this component.

2) 3.3V IO - Remove R27, Fit R28, *Replace Y1 (change from 16MHz to 10MHz), *Replace Y2
(change from 16MHz to 8MHz).

3) Both 5V and 3V3, selected through JP4 - Remove R27, Remove R28, Fit JP4, *Replace Y1
(change from 16MHz to 10MHz), *Replace Y2 (change from 16MHz to 8MHz).

*Note: The 16MHz crystals are not recommended for 3.3V operation. We need to adjust their
values.

IMPORTANT: Once you change the crystal value, you may need to re-compile your source
code.

About JP3:
1) DebugWire support - Short 1&2. It was added to support possible debugWire debugging
(programming?) of 328P through 16U2. In this case, the 16U2 needs to have a correct firmware
and has to behave as a debugWire tool.

2) ISP programmer mode - Short 2&3. In this case, take a cable and connect J5 & J6 together.
Upload AVRISP MKII firmware into 16U2 and you can program 328P. Example of AVRISP
MKII firmware can be found at LUFA projects: http://www.fourwalledcubicle.com/LUFA.php
(Tip: remap LEDs of the default AVRISP MKII LUFA project to the RX and TX LEDs on the
28Pin board)

3) ISP header - Short 3 & 4. In this mode, the ICSP1 header is used as a standard ISP header

About JP1:
1) Autoreset Enabled - Short 1&2. In this case, 16U2 is used to reset 328P when firmware
inside 328P is updated from Arduino IDE.

2) 16U2 DFU mode Enabled - Short 2&3. 16U2 HWB pin is sampled by 16U2 during RESET. If
pulled low, after Reset, the 16U2 will go into DFU mode (it's the mode when you can flash
16U2 firmware through USB and Atmel Flip software: http://www.atmel.com/tools/flip.aspx ).

This board can be powered from micro USB
connector (J7) or a single +3.3V power rail
(through J1 pin 4). If +3.3V is used, fit R26 and
R28. In this case, JP4 & R27 must NOT be
fitted. Otherwise the board may be damaged.

Pin 8 (VIN) is not supported

MISO
MOSI
SS

(PCINT7/XTAL2/TOSC2) PB7 10 | IO9

AD5/SCL
AD4/SDA

AD2
AD1
AD0

Mounting holes 7.4mm pad 3.2mm drill
BOARD MOUNTING HOLES
ONE IN EACH CORNER
FIDUCIALS

IO7
IO1 | | | 1 1 2 2 3 3 4 4 5 5 6 6 7 7 8 8
IO3
IO2

IO5
IO4

GND_2 22 | IO0

This LED is inverted:
- SCK High = LED OFF
- SCK Low = LED ON

LAYOUT NOTE:
1) Route all the POWER tracks with minimum track width 0.4mm.
2) Route all the other tracks by 0.4mm and change them by the end of
the design to 0.2mm. To change all of them at once, use this filter
"(not InNet('+*') and not InNet('GND')) and IsTrack and (OnLayer('L1')
or OnLayer ('L2'))" and then set 0.2mm width in PCB Inspector panel.

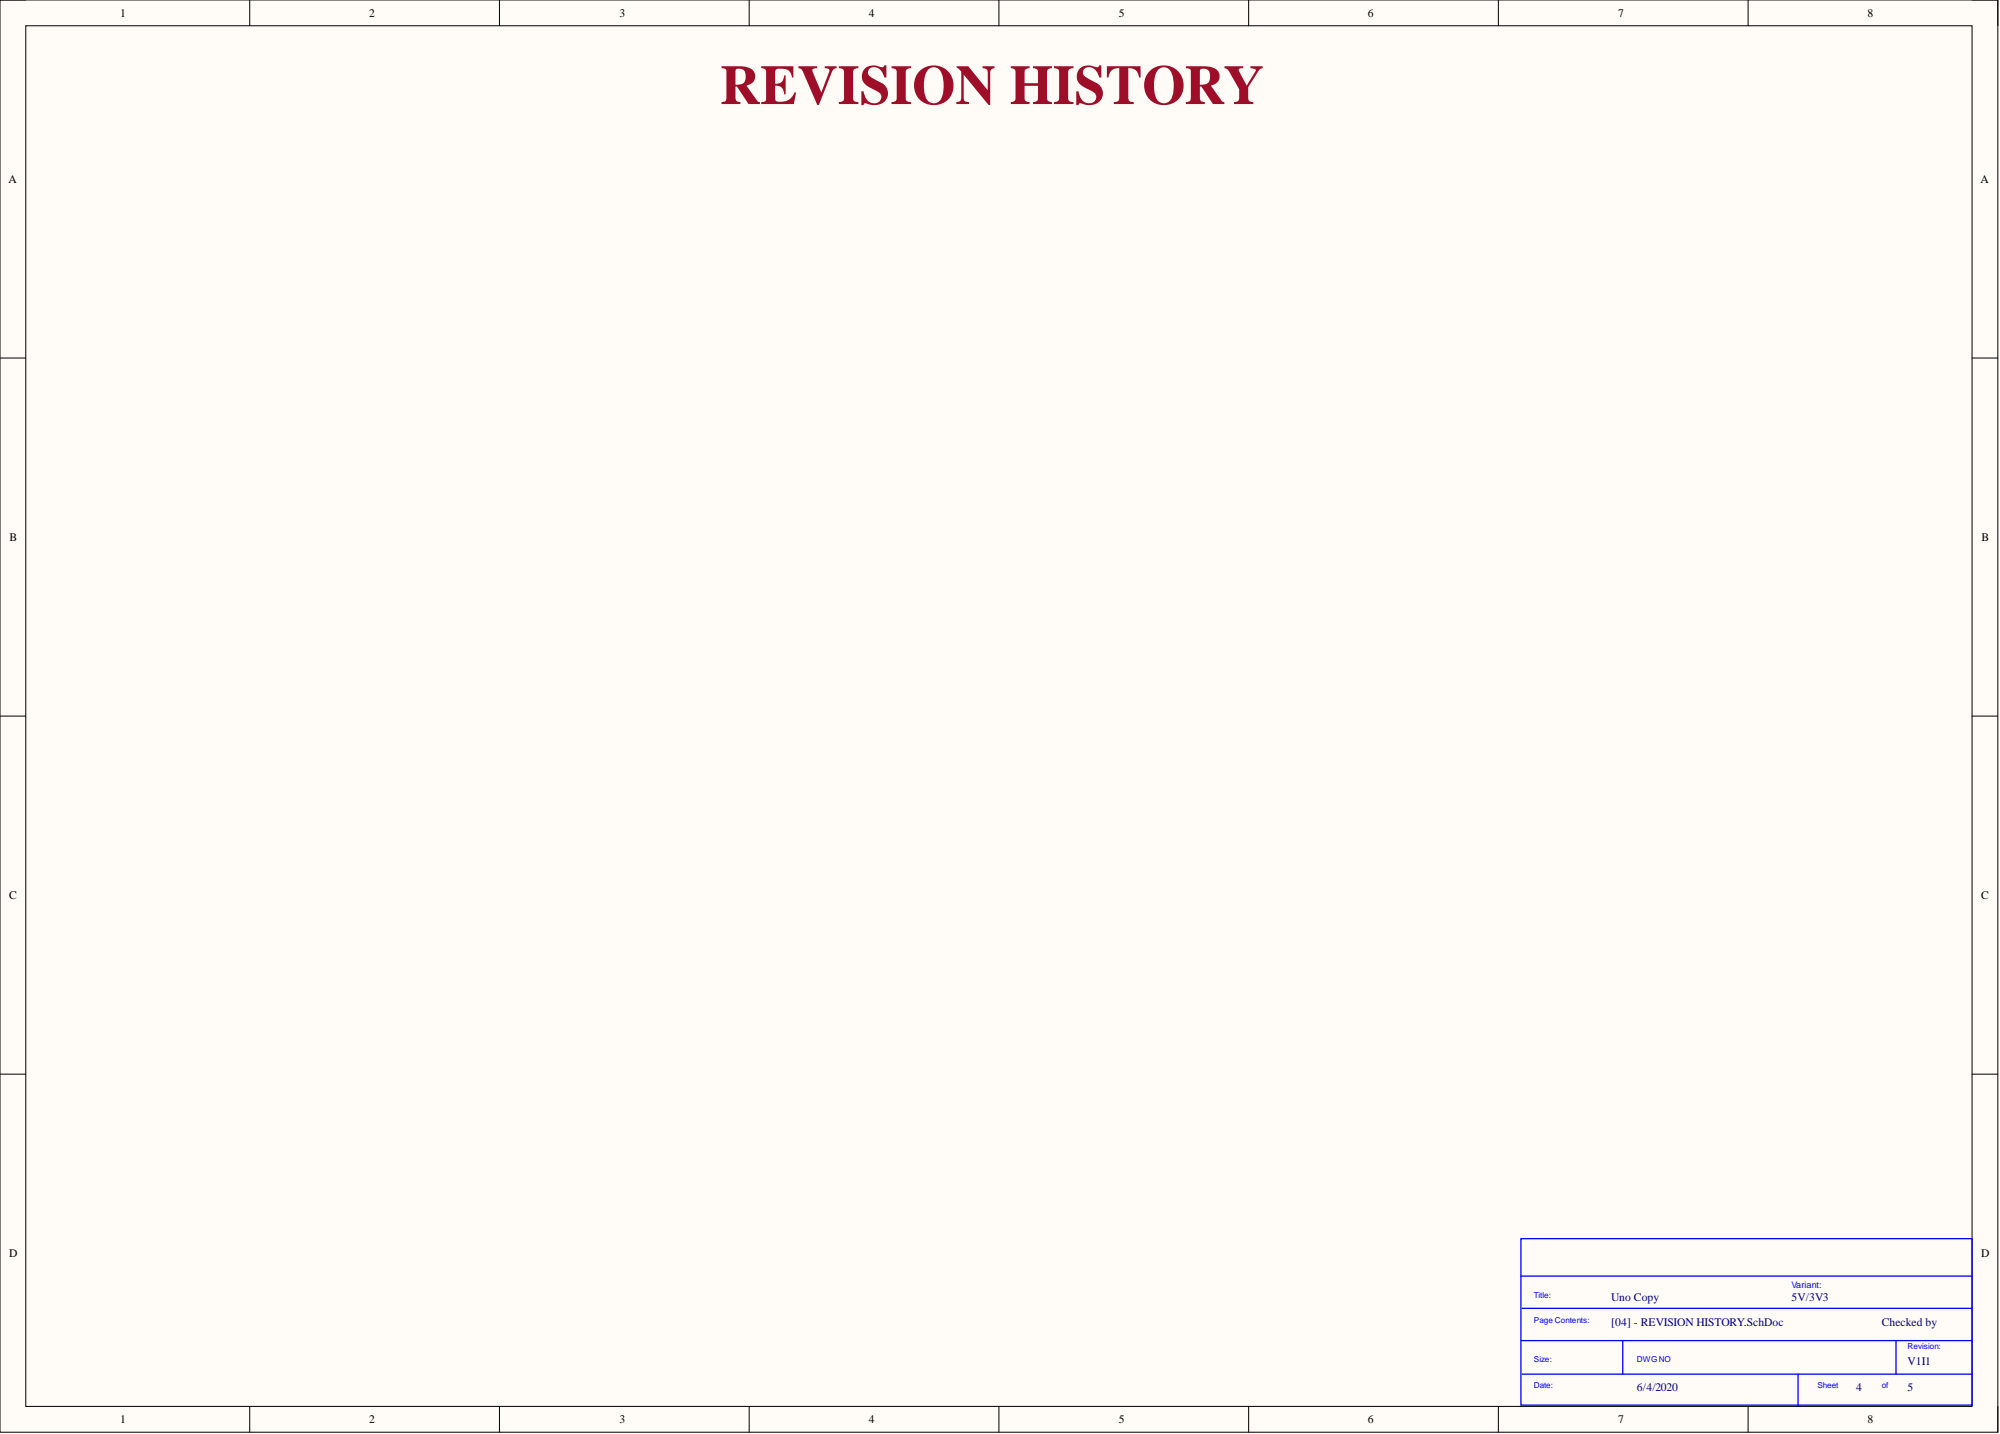
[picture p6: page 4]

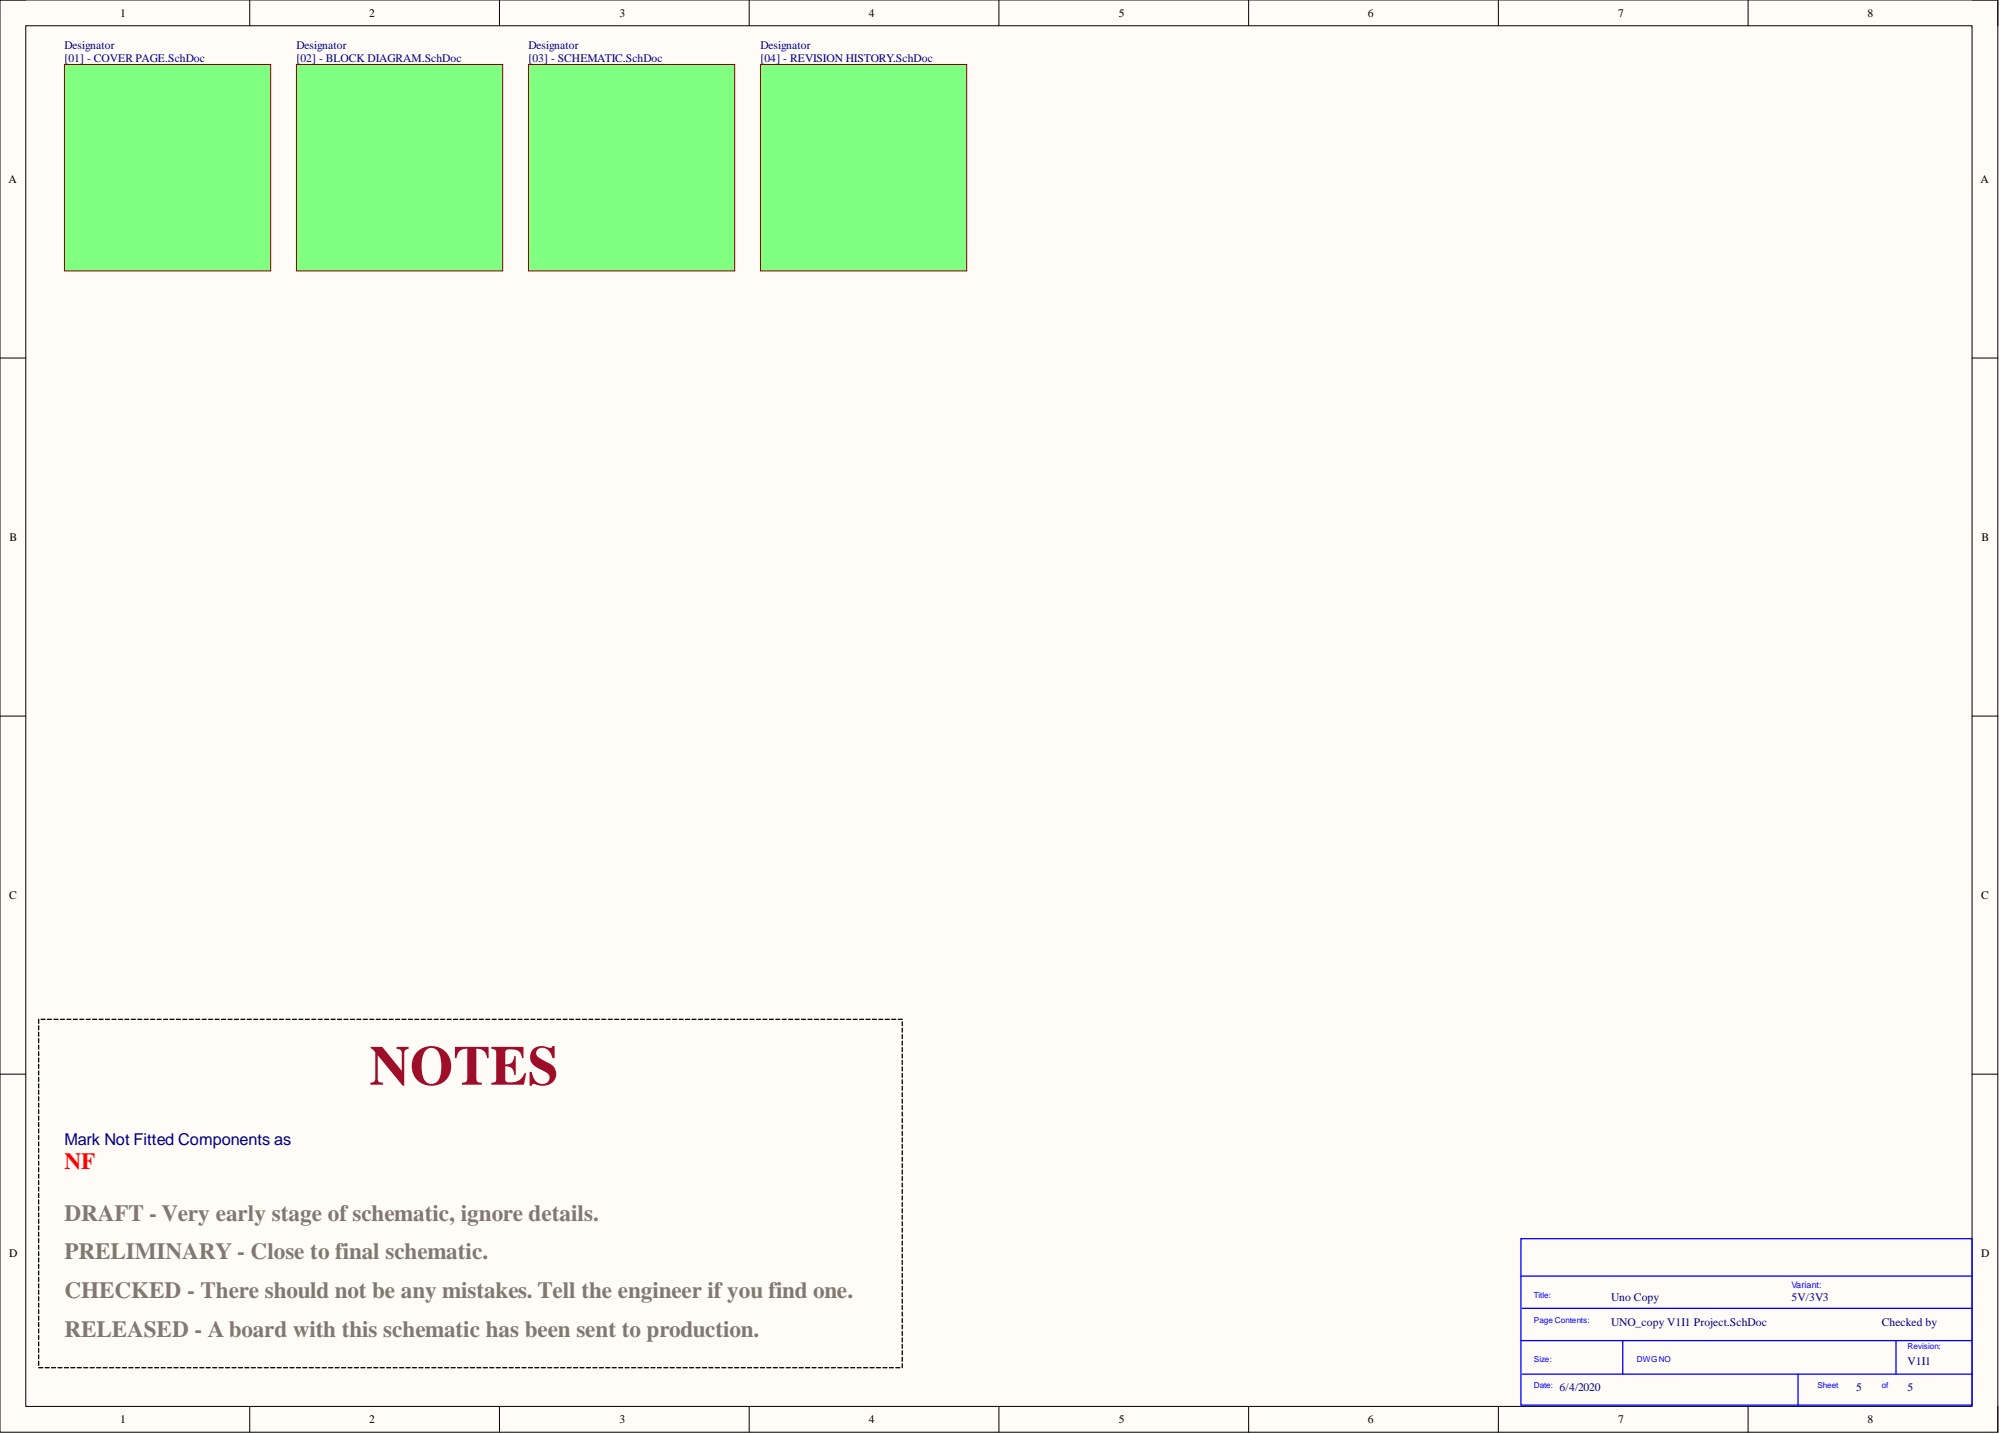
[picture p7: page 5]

Mark Not Fitted Components as

DRAFT - Very early stage of schematic, ignore details.
PRELIMINARY - Close to final schematic.
CHECKED - There should not be any mistakes. Tell the engineer if you find one.
RELEASED - A board with this schematic has been sent to production.

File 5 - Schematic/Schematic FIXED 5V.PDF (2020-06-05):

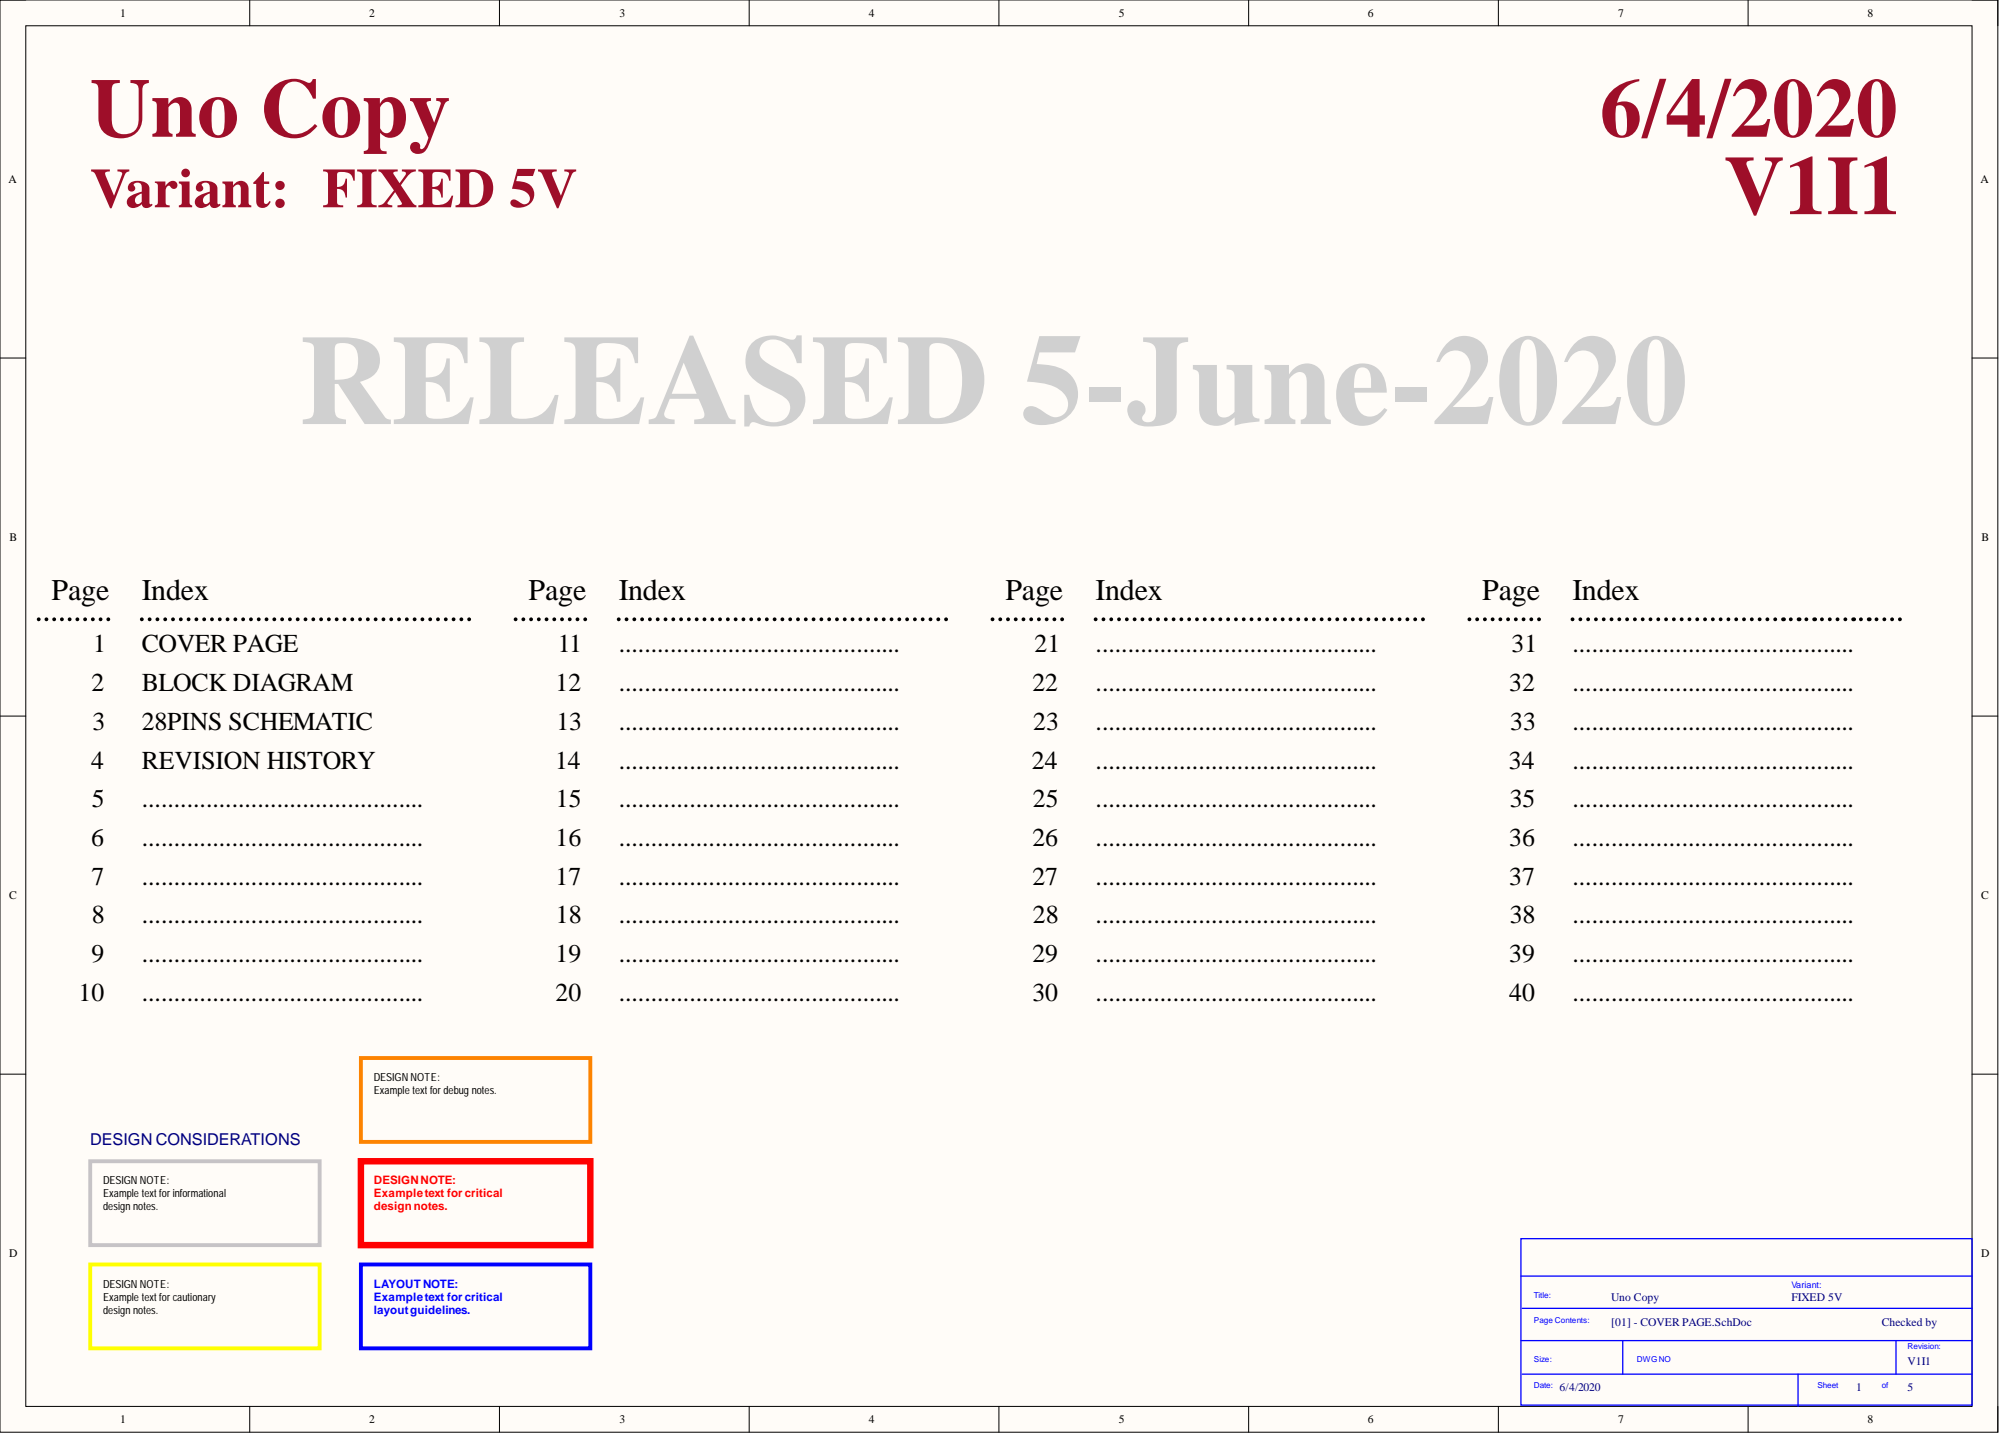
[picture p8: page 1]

DESIGN NOTE:
Example text for debug notes.

Example text for informational
design notes.

Example text for critical

Example text for cautionary

LAYOUT NOTE:
layout guidelines.

Size: | DWG NO | Revision: V1I1

Date: | Sheet of

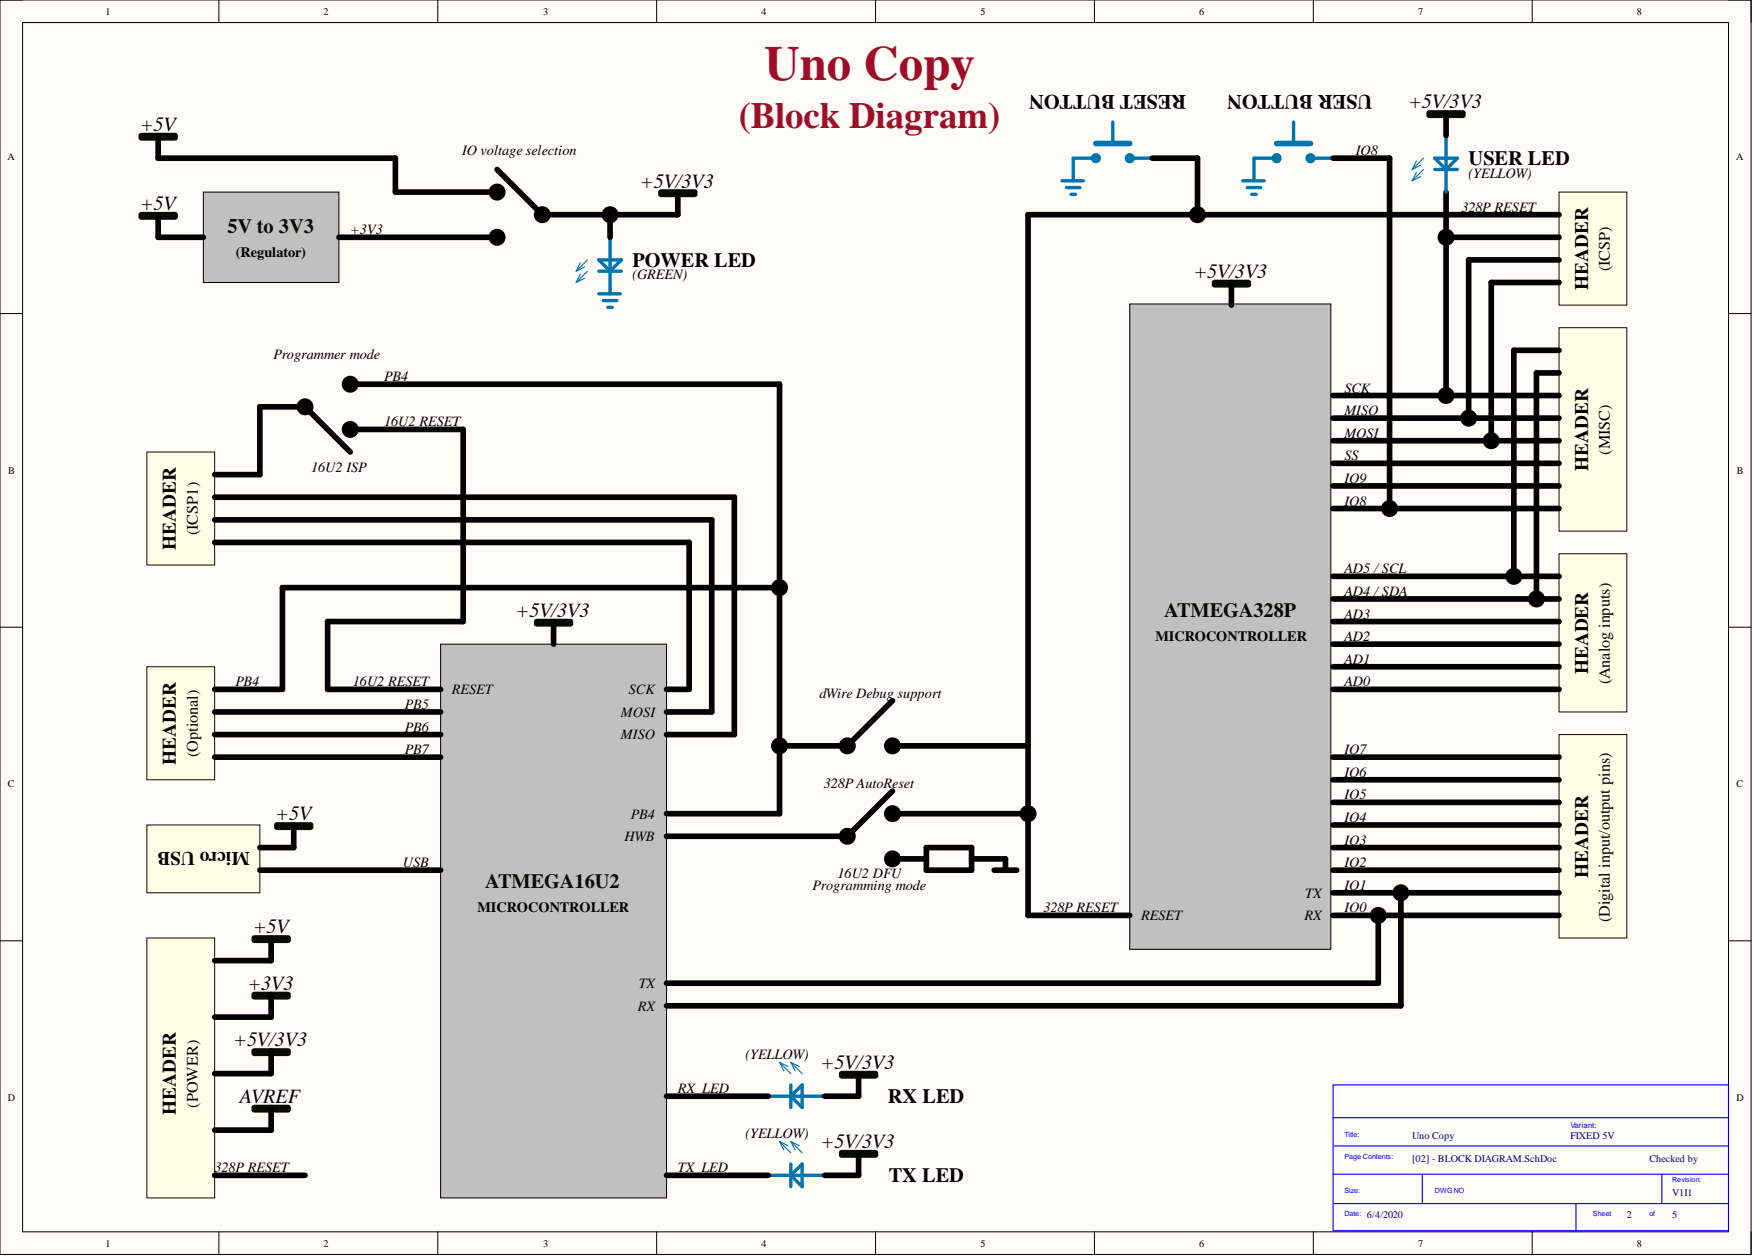
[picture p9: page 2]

MISO
MOSI
SS
IO9
IO8

AD5 / SCL
AD4 / SDA

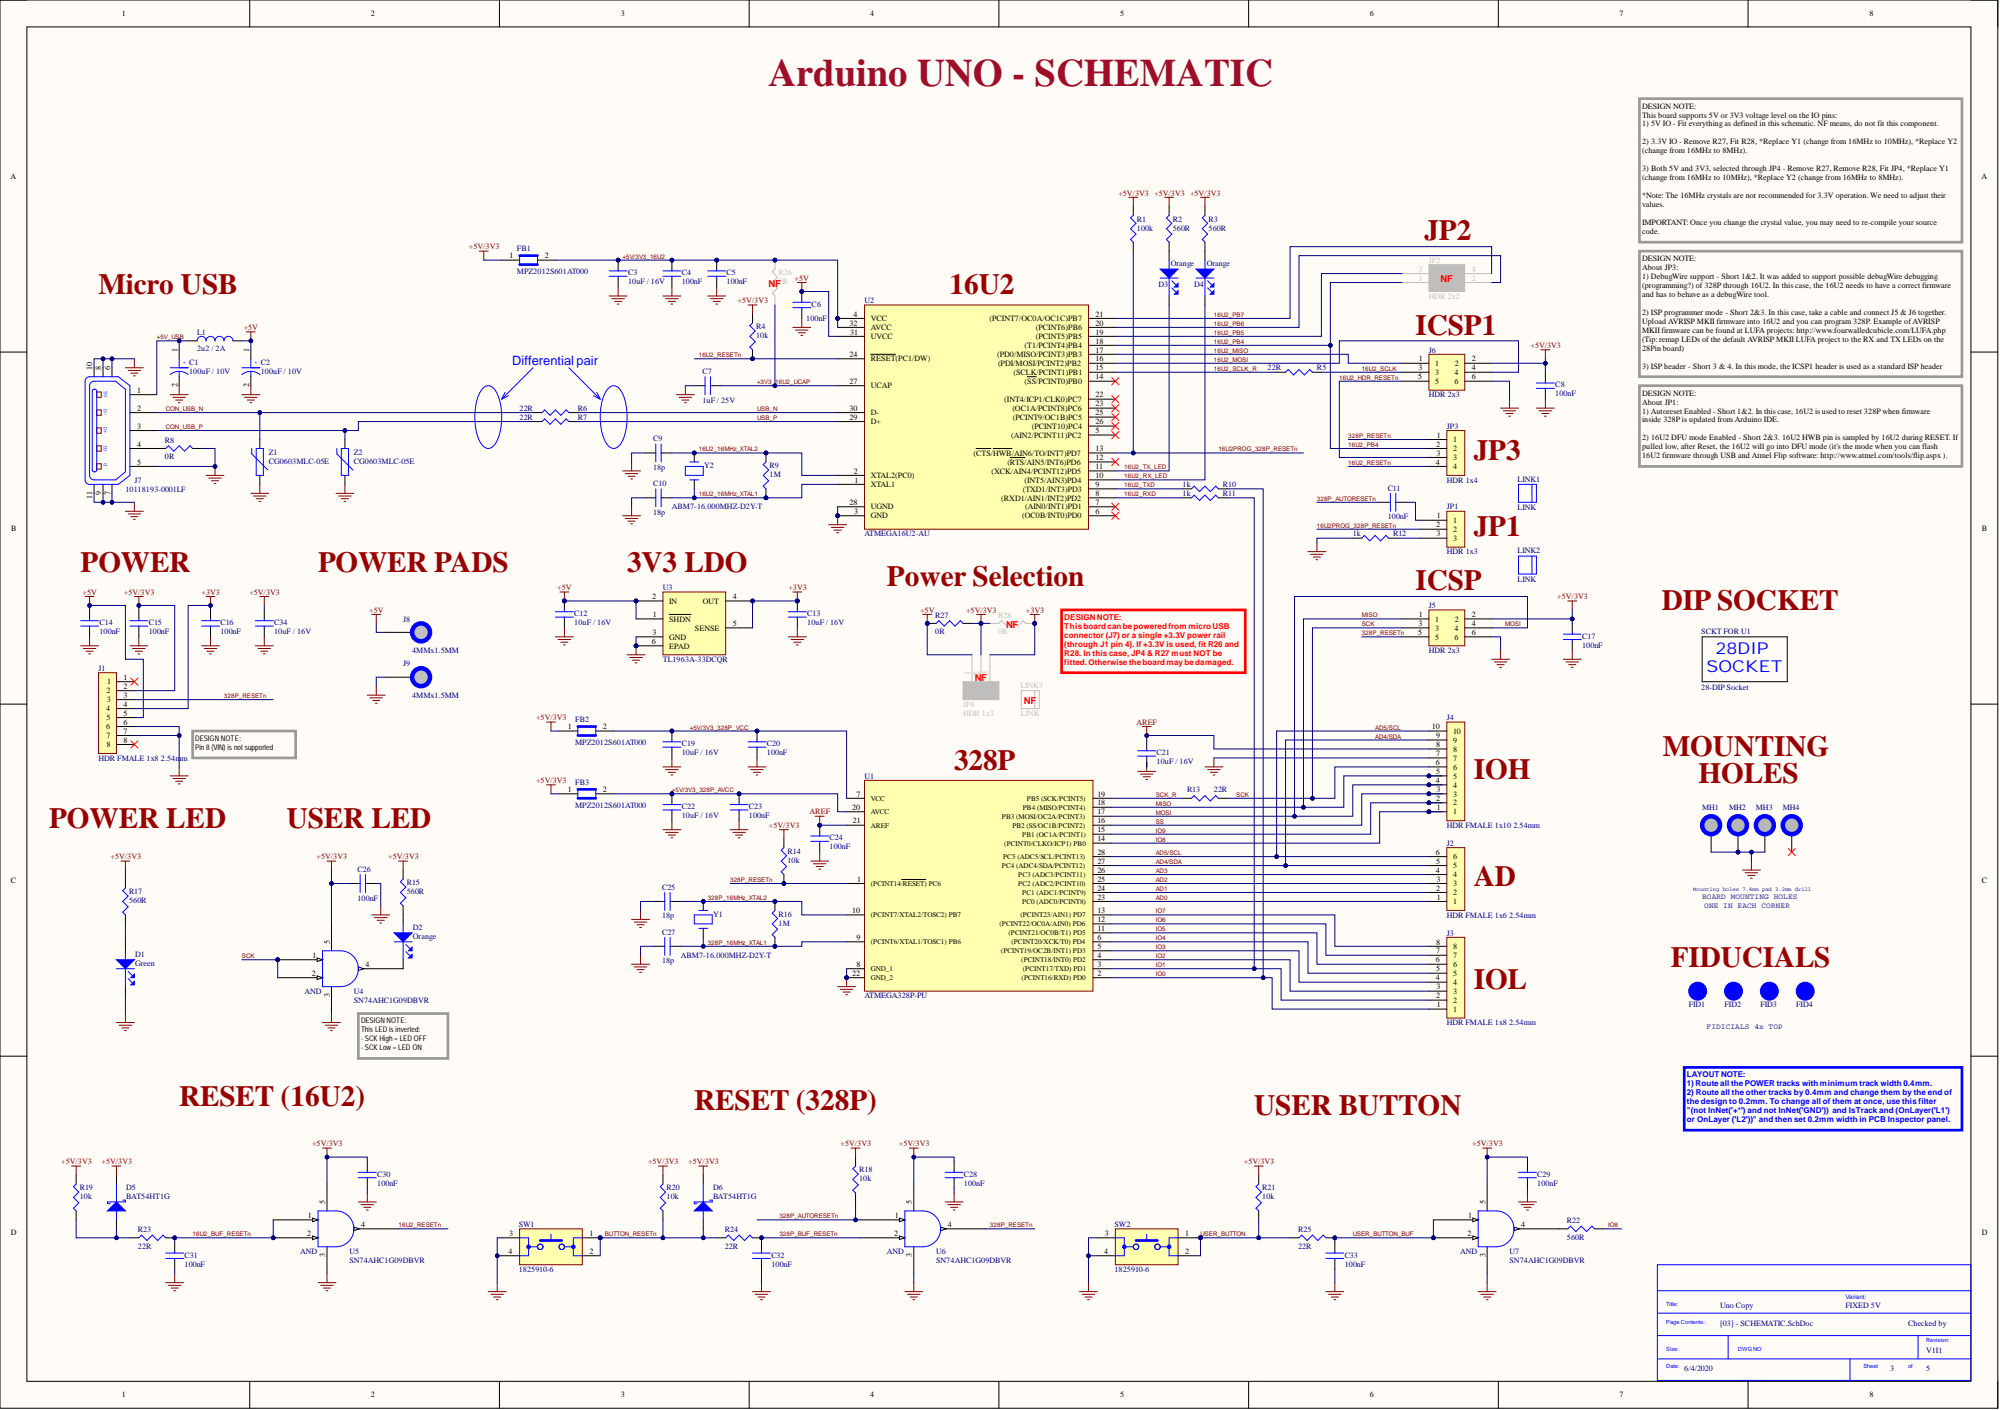
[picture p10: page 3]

DESIGN NOTE:
This board supports 5V or 3V3 voltage level on the IO pins:
1) 5V IO - Fit everything as defined in this schematic. NF means, do not fit this component.

2) 3.3V IO - Remove R27, Fit R28, *Replace Y1 (change from 16MHz to 10MHz), *Replace Y2
(change from 16MHz to 8MHz).

3) Both 5V and 3V3, selected through JP4 - Remove R27, Remove R28, Fit JP4, *Replace Y1
(change from 16MHz to 10MHz), *Replace Y2 (change from 16MHz to 8MHz).

*Note: The 16MHz crystals are not recommended for 3.3V operation. We need to adjust their
values.

IMPORTANT: Once you change the crystal value, you may need to re-compile your source
code.

About JP3:
1) DebugWire support - Short 1&2. It was added to support possible debugWire debugging
(programming?) of 328P through 16U2. In this case, the 16U2 needs to have a correct firmware
and has to behave as a debugWire tool.

2) ISP programmer mode - Short 2&3. In this case, take a cable and connect J5 & J6 together.
Upload AVRISP MKII firmware into 16U2 and you can program 328P. Example of AVRISP
MKII firmware can be found at LUFA projects: http://www.fourwalledcubicle.com/LUFA.php
(Tip: remap LEDs of the default AVRISP MKII LUFA project to the RX and TX LEDs on the
28Pin board)

3) ISP header - Short 3 & 4. In this mode, the ICSP1 header is used as a standard ISP header

About JP1:
1) Autoreset Enabled - Short 1&2. In this case, 16U2 is used to reset 328P when firmware
inside 328P is updated from Arduino IDE.

2) 16U2 DFU mode Enabled - Short 2&3. 16U2 HWB pin is sampled by 16U2 during RESET. If
pulled low, after Reset, the 16U2 will go into DFU mode (it's the mode when you can flash
16U2 firmware through USB and Atmel Flip software: http://www.atmel.com/tools/flip.aspx ).

This board can be powered from micro USB
connector (J7) or a single +3.3V power rail
(through J1 pin 4). If +3.3V is used, fit R26 and
R28. In this case, JP4 & R27 must NOT be
fitted. Otherwise the board may be damaged.

Pin 8 (VIN) is not supported

MISO
MOSI
SS

(PCINT7/XTAL2/TOSC2) PB7 10 | IO9

AD5/SCL
AD4/SDA

AD2
AD1
AD0

Mounting holes 7.4mm pad 3.2mm drill
BOARD MOUNTING HOLES
ONE IN EACH CORNER
FIDUCIALS

IO7
IO1 | | | 1 1 2 2 3 3 4 4 5 5 6 6 7 7 8 8
IO3
IO2

IO5
IO4

GND_2 22 | IO0

This LED is inverted:
- SCK High = LED OFF
- SCK Low = LED ON

LAYOUT NOTE:
1) Route all the POWER tracks with minimum track width 0.4mm.
2) Route all the other tracks by 0.4mm and change them by the end of
the design to 0.2mm. To change all of them at once, use this filter
"(not InNet('+*') and not InNet('GND')) and IsTrack and (OnLayer('L1')
or OnLayer ('L2'))" and then set 0.2mm width in PCB Inspector panel.

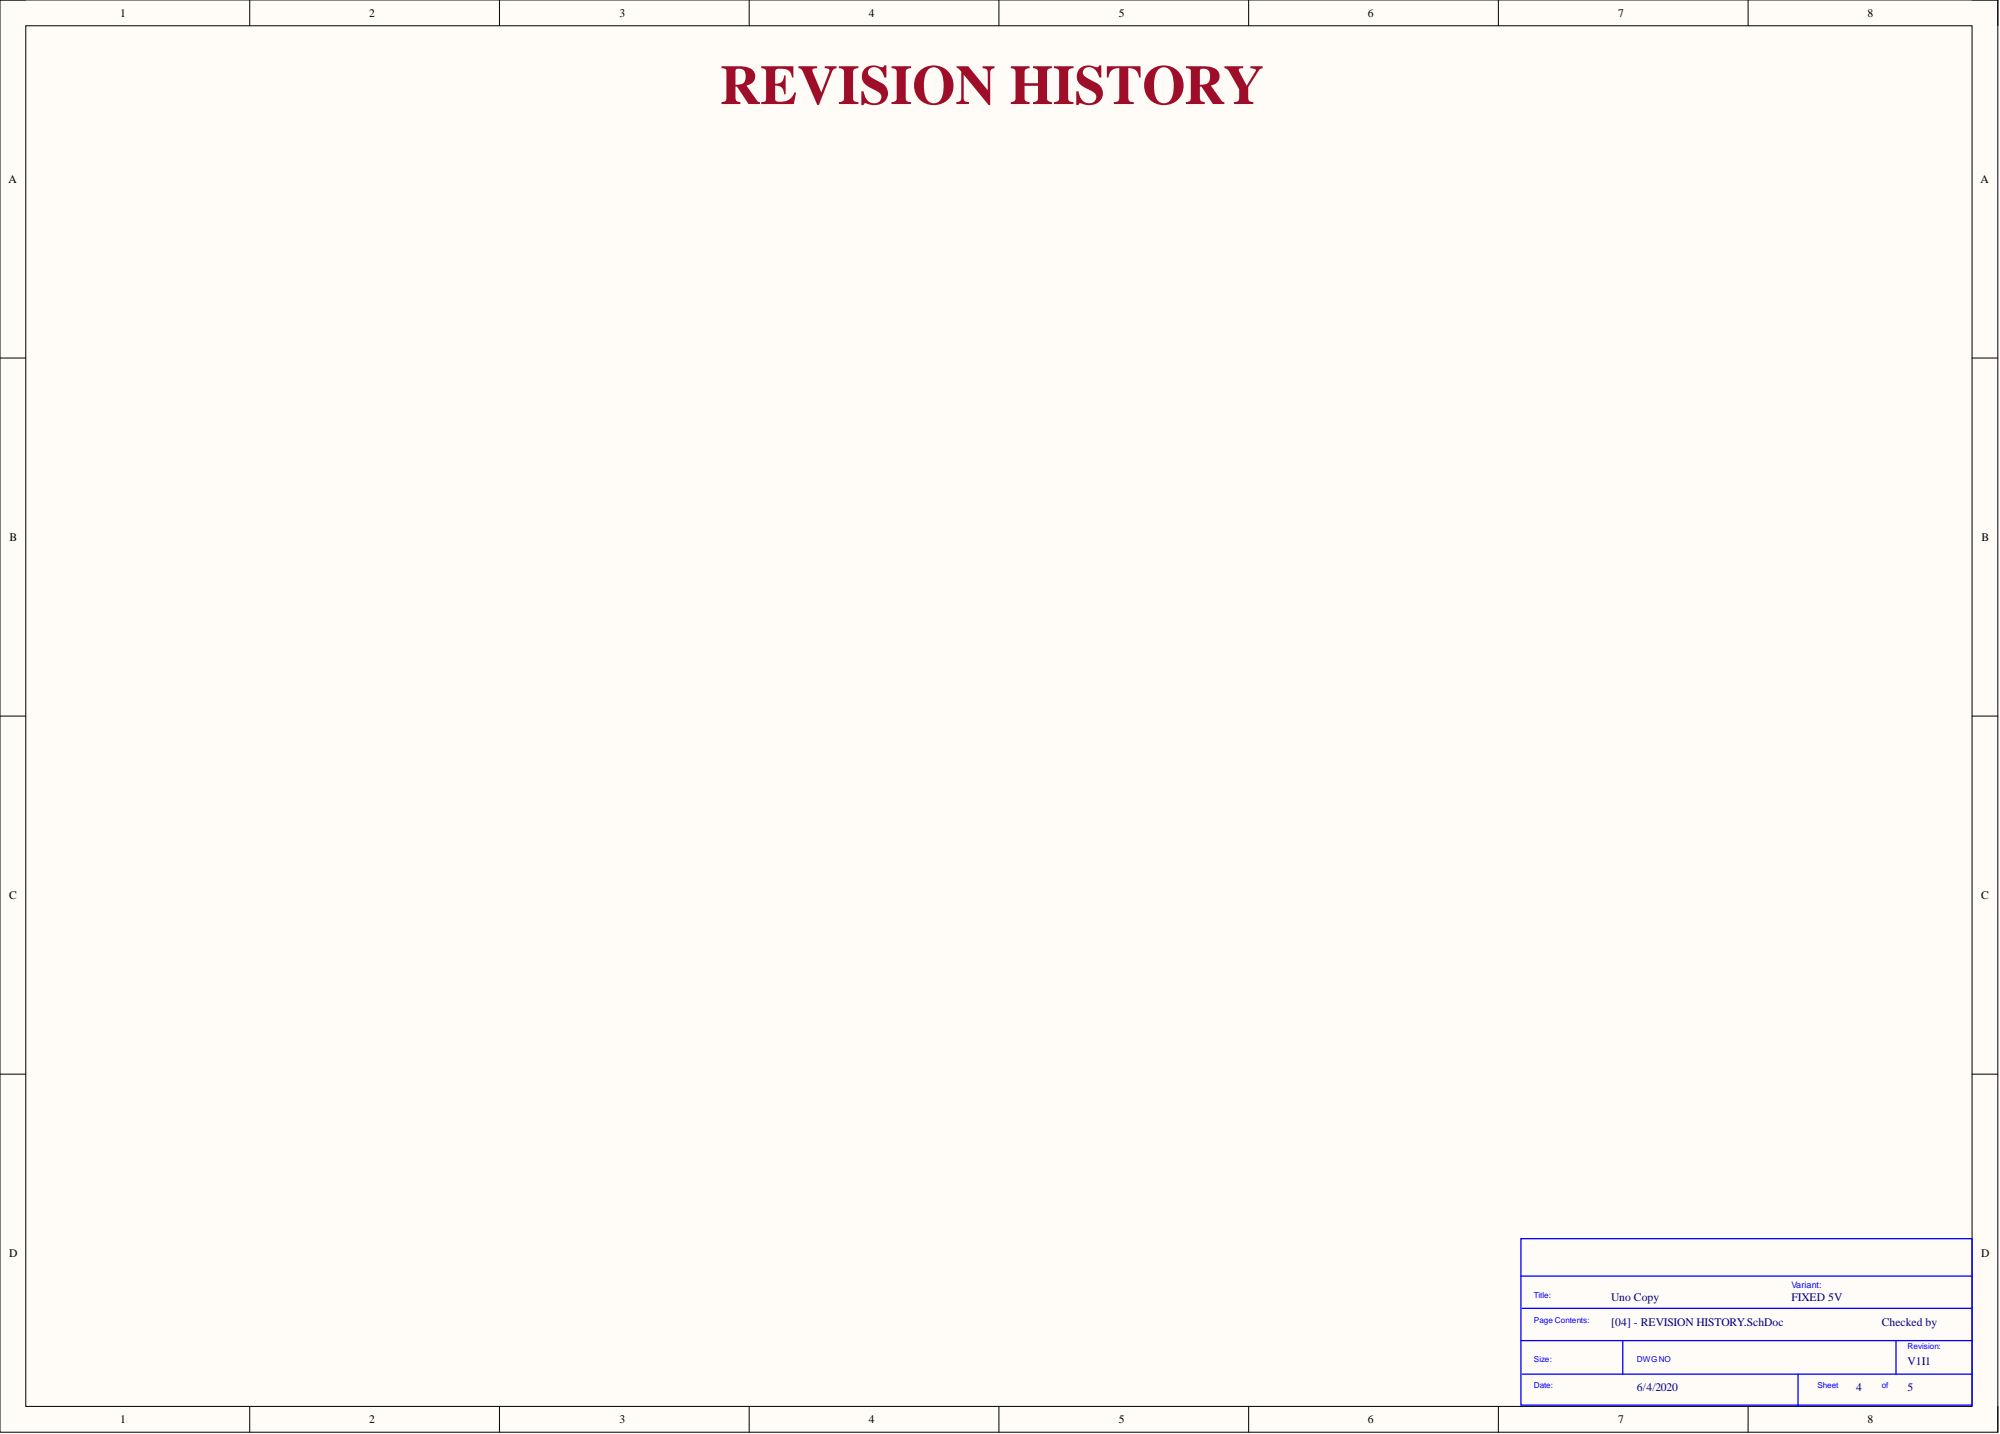
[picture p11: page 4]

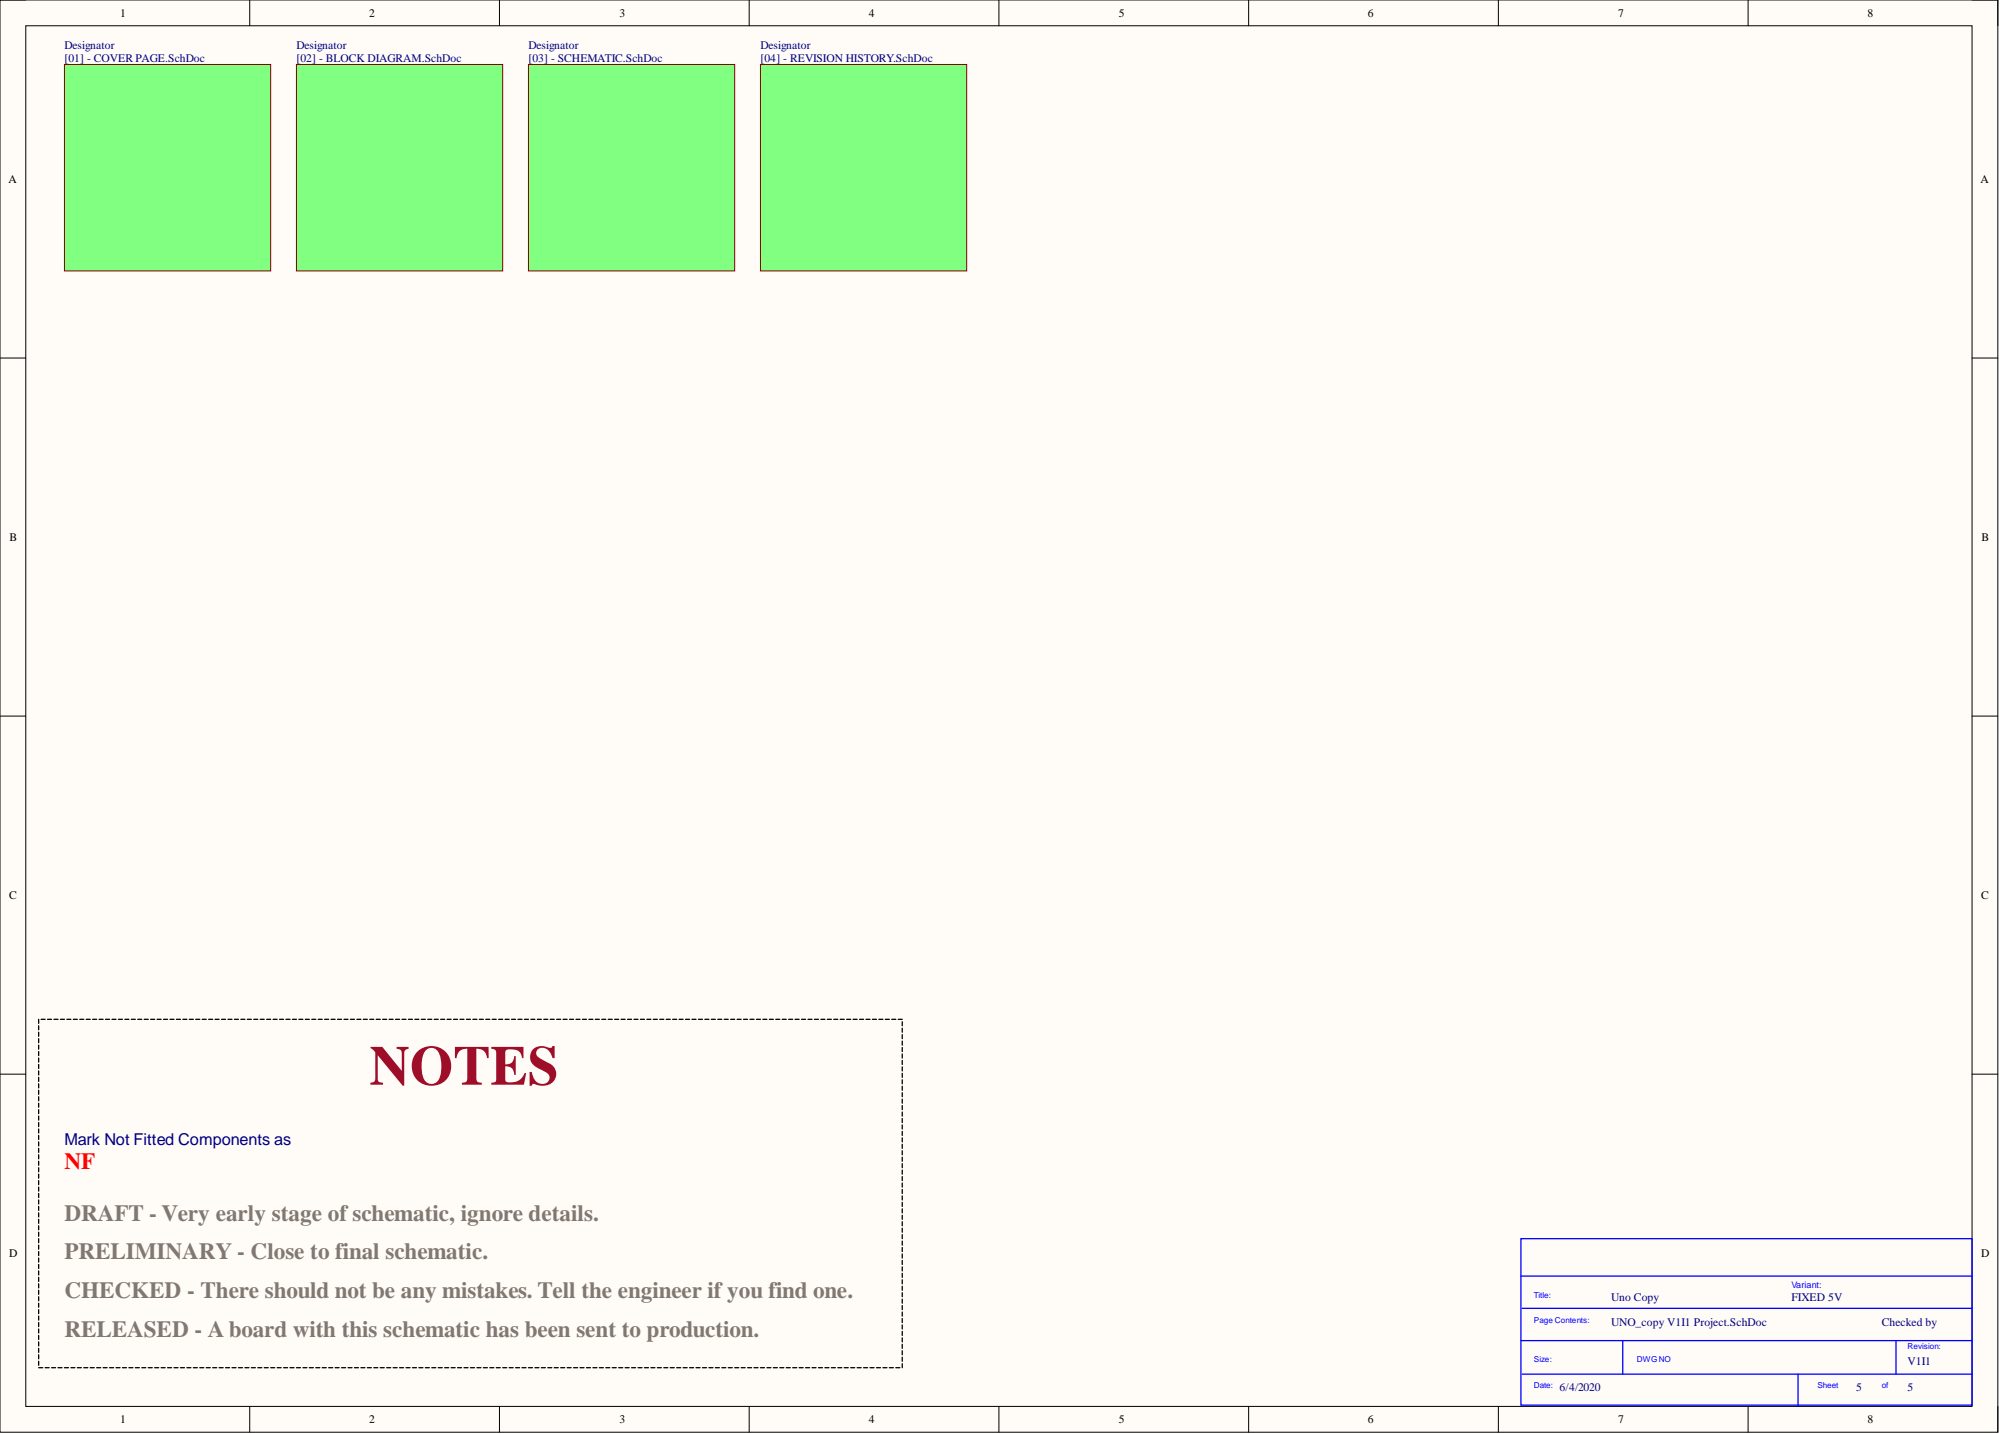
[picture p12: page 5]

Mark Not Fitted Components as

DRAFT - Very early stage of schematic, ignore details.
PRELIMINARY - Close to final schematic.
CHECKED - There should not be any mistakes. Tell the engineer if you find one.
RELEASED - A board with this schematic has been sent to production.

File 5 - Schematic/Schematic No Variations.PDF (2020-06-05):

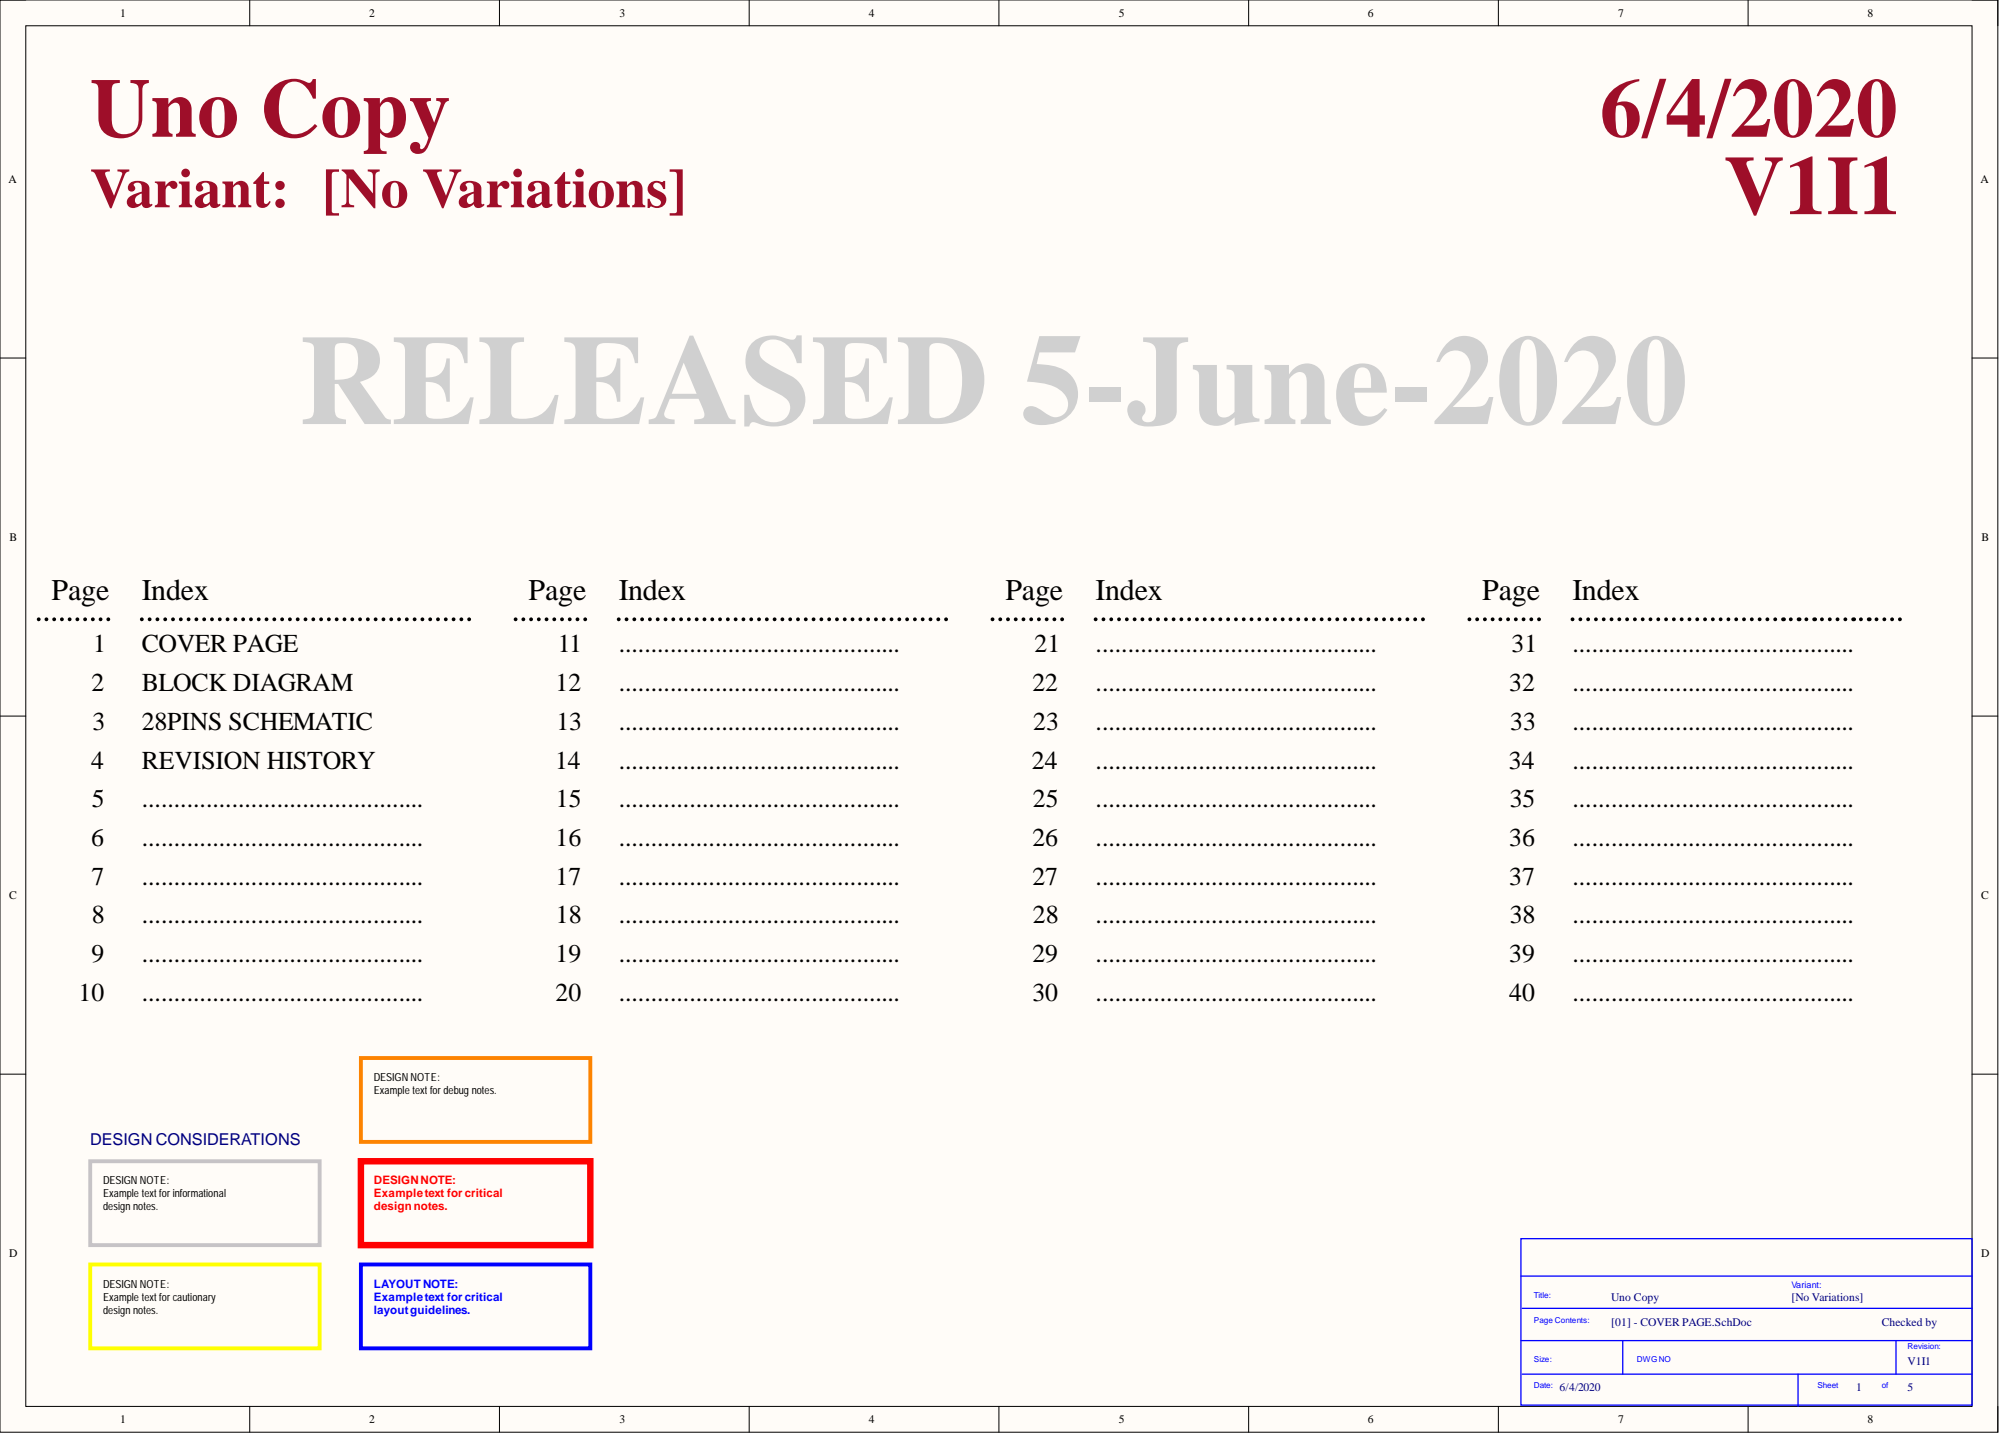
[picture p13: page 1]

DESIGN NOTE:
Example text for debug notes.

Example text for informational
design notes.

Example text for critical

Example text for cautionary

LAYOUT NOTE:
layout guidelines.

Size: | DWG NO | Revision: V1I1

Date: | Sheet of

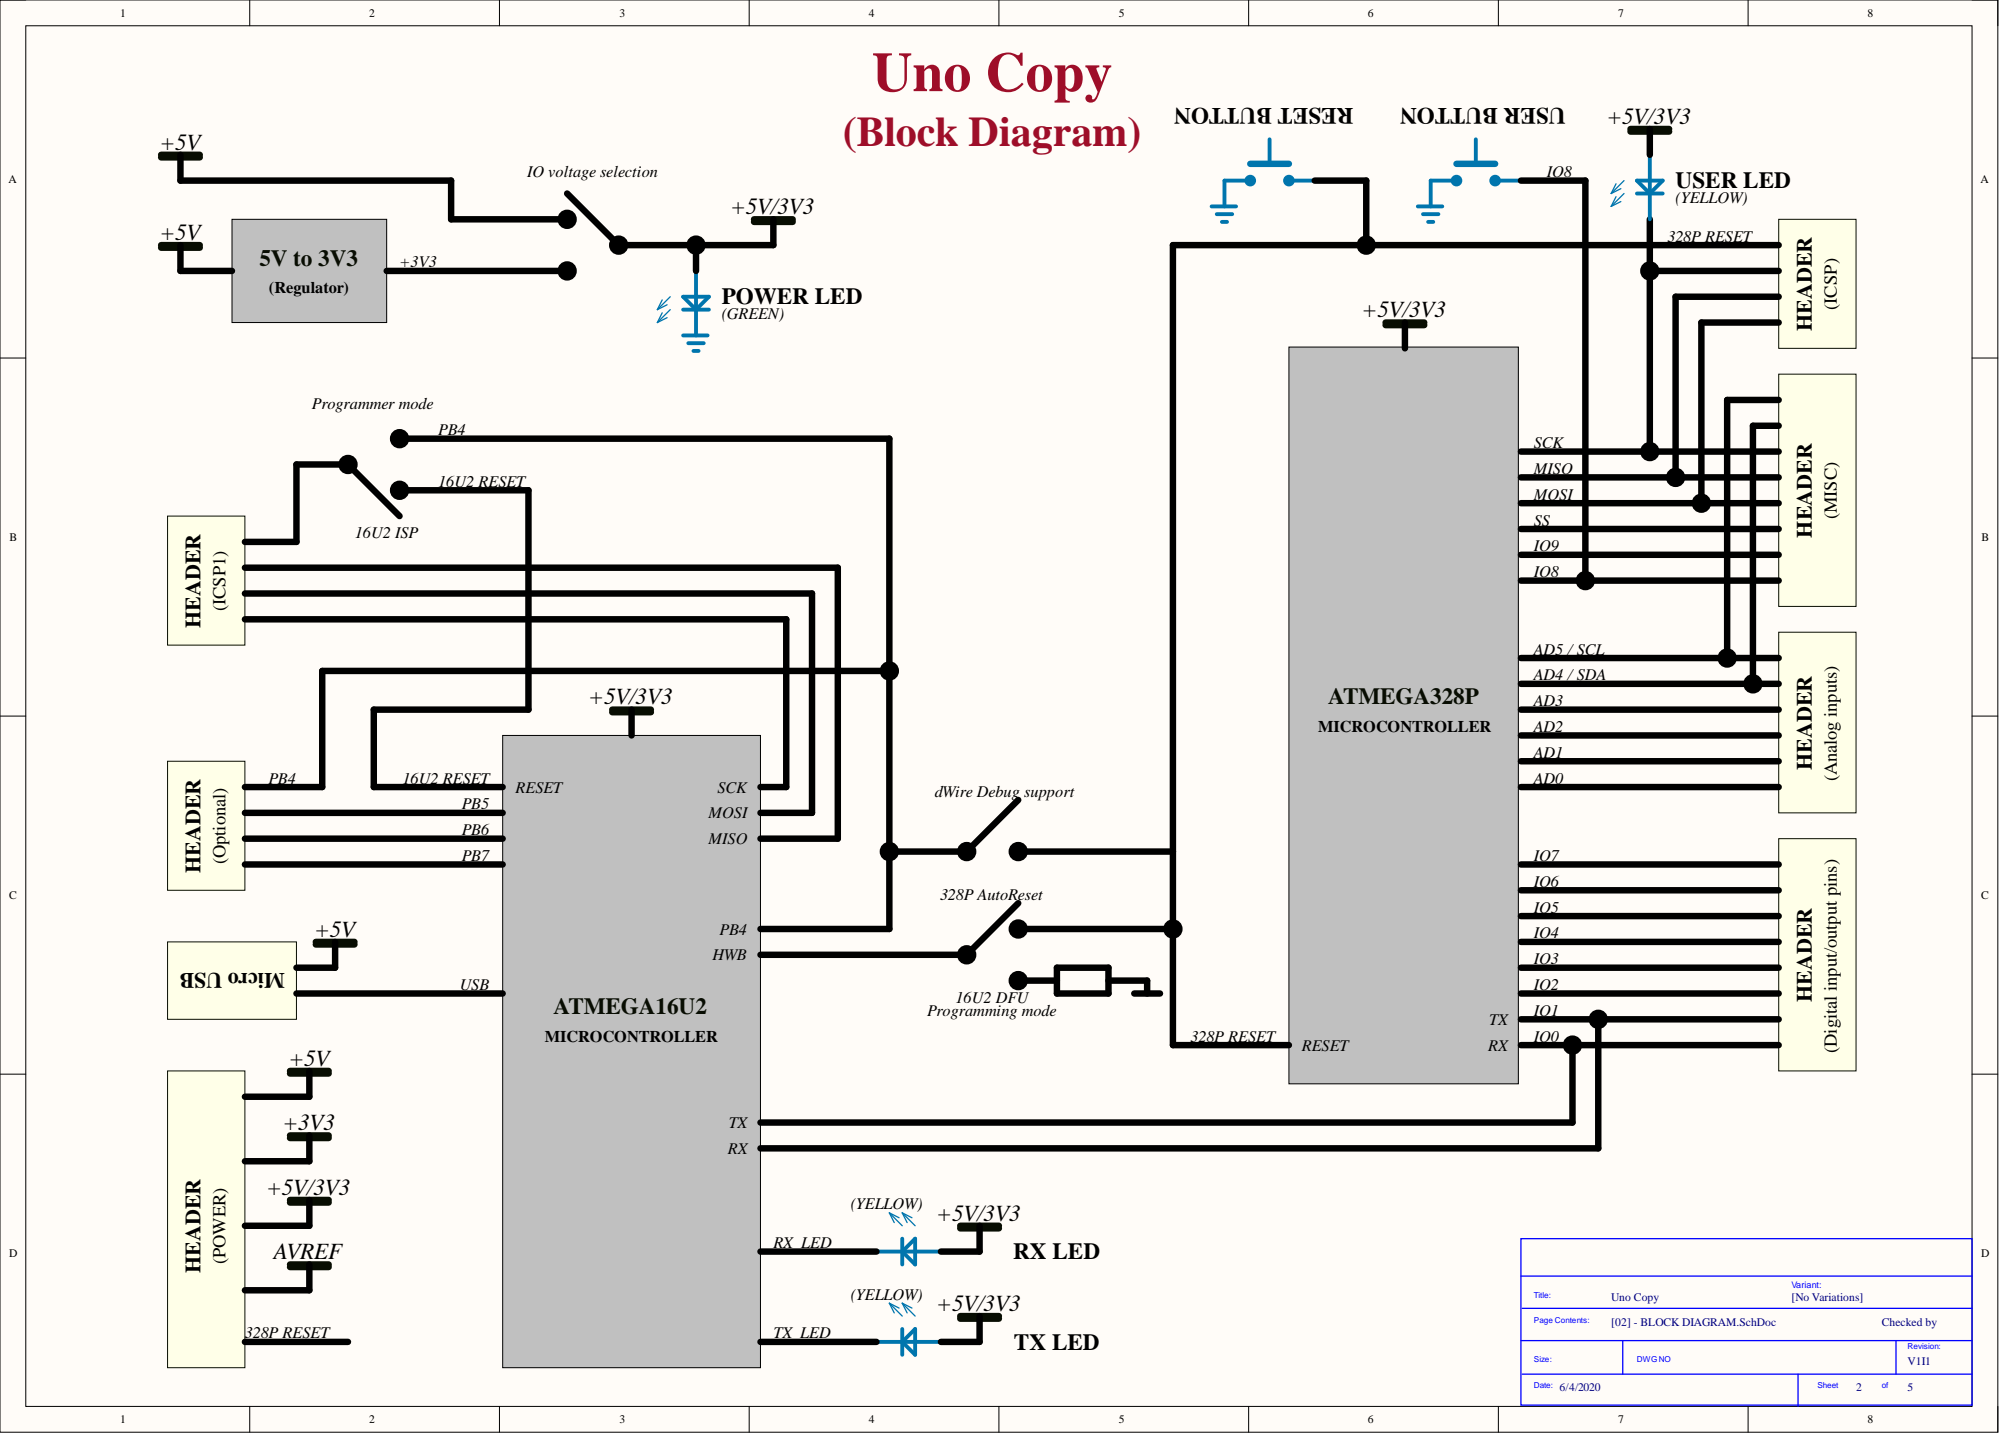
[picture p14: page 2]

MISO
MOSI
SS
IO9
IO8

AD5 / SCL
AD4 / SDA


DESIGN NOTE:
This board supports 5V or 3V3 voltage level on the IO pins:
1) 5V IO - Fit everything as defined in this schematic. NF means, do not fit this component.

2) 3.3V IO - Remove R27, Fit R28, *Replace Y1 (change from 16MHz to 10MHz), *Replace Y2
(change from 16MHz to 8MHz).

3) Both 5V and 3V3, selected through JP4 - Remove R27, Remove R28, Fit JP4, *Replace Y1
(change from 16MHz to 10MHz), *Replace Y2 (change from 16MHz to 8MHz).

*Note: The 16MHz crystals are not recommended for 3.3V operation. We need to adjust their
values.

IMPORTANT: Once you change the crystal value, you may need to re-compile your source
code.

About JP3:
1) DebugWire support - Short 1&2. It was added to support possible debugWire debugging
(programming?) of 328P through 16U2. In this case, the 16U2 needs to have a correct firmware
and has to behave as a debugWire tool.

2) ISP programmer mode - Short 2&3. In this case, take a cable and connect J5 & J6 together.
Upload AVRISP MKII firmware into 16U2 and you can program 328P. Example of AVRISP
MKII firmware can be found at LUFA projects: http://www.fourwalledcubicle.com/LUFA.php
(Tip: remap LEDs of the default AVRISP MKII LUFA project to the RX and TX LEDs on the
28Pin board)

3) ISP header - Short 3 & 4. In this mode, the ICSP1 header is used as a standard ISP header

About JP1:
1) Autoreset Enabled - Short 1&2. In this case, 16U2 is used to reset 328P when firmware
inside 328P is updated from Arduino IDE.

2) 16U2 DFU mode Enabled - Short 2&3. 16U2 HWB pin is sampled by 16U2 during RESET. If
pulled low, after Reset, the 16U2 will go into DFU mode (it's the mode when you can flash
16U2 firmware through USB and Atmel Flip software: http://www.atmel.com/tools/flip.aspx ).

This board can be powered from micro USB
connector (J7) or a single +3.3V power rail
(through J1 pin 4). If +3.3V is used, fit R26 and
R28. In this case, JP4 & R27 must NOT be
fitted. Otherwise the board may be damaged.

Pin 8 (VIN) is not supported

MISO
MOSI
SS

(PCINT7/XTAL2/TOSC2) PB7 10 | IO9

AD5/SCL
AD4/SDA

AD2
AD1
AD0

Mounting holes 7.4mm pad 3.2mm drill
BOARD MOUNTING HOLES
ONE IN EACH CORNER
FIDUCIALS

IO7
IO1 | | | 1 1 2 2 3 3 4 4 5 5 6 6 7 7 8 8
IO3
IO2

IO5
IO4

GND_2 22 | IO0

This LED is inverted:
- SCK High = LED OFF
- SCK Low = LED ON

LAYOUT NOTE:
1) Route all the POWER tracks with minimum track width 0.4mm.
2) Route all the other tracks by 0.4mm and change them by the end of
the design to 0.2mm. To change all of them at once, use this filter
"(not InNet('+*') and not InNet('GND')) and IsTrack and (OnLayer('L1')
or OnLayer ('L2'))" and then set 0.2mm width in PCB Inspector panel.



Mark Not Fitted Components as

DRAFT - Very early stage of schematic, ignore details.
PRELIMINARY - Close to final schematic.
CHECKED - There should not be any mistakes. Tell the engineer if you find one.
RELEASED - A board with this schematic has been sent to production.








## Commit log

2020-06-05 files uploading
    [4)BOM purchasing-UNO_copy V1I1(5V_3V3).xlsx, 4)BOM purchasing-UNO_copy V1I1(FIXED 5V).xlsx, 5)Component Reference BOM-UNO_copy V1I1(5V_3V3).xlsx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]
2020-06-05 quick_access 3D model added
    [quick_view 3D model.stl]
